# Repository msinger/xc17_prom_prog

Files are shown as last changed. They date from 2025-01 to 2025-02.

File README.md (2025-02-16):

XC17xxx PROM Programmer
=======================

Tool for programming Xilinx XC17xxx families of PROM chips that are used for storing the configuration
bitstream of the Spartan FPGA.

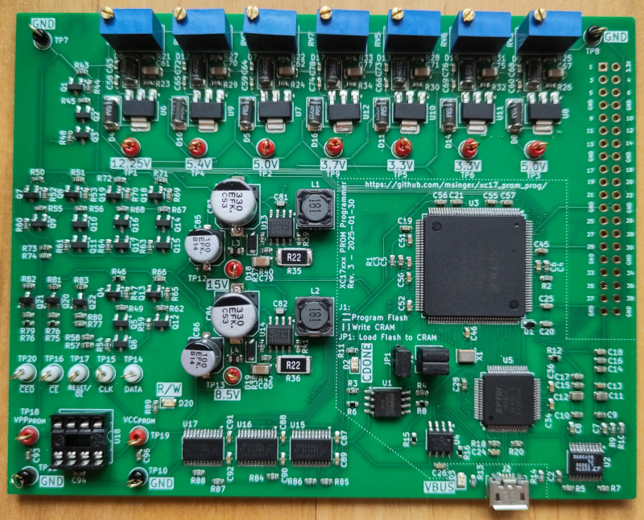
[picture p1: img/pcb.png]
PCB


I developed this programmer to be able to program the PROM chips used in the Wide-Boy64. The Wide-Boy64
CGB uses the XC1701L, and the [Wide-Boy64 AGB](http://iceboy.a-singer.de/doc/wide_boy.html) uses the XC17S20XL.

I originally thought that the Wide-Boy64 CGB uses the XC1701 chip (without the L at the end), because that's
how those chips are labeled on their package. After buying some of those XC1701 chips and reading out their
device ID, I realized that they actually are XC1701L chips. This makes sense by the way, since the Spartan
XC4010XL FPGA inside the Wide-Boy64 CGB has 3.3&nbsp;V IO voltage, which matches the XC1701L PROM. The XC1701
is a 5&nbsp;V device.

You can still buy the XC17S20XL chips here:
- https://de.aliexpress.com/item/1005006854844265.html
- https://www.win-source.net/products/detail/xilinx-inc/xc17s20lpc.html
- https://www.win-source.net/products/detail/xilinx-inc/xc17s20xlpd8c.html

You can still buy a very limited supply of the XC1701L chips here:
- https://www.win-source.net/products/detail/xilinx-inc/xc1701pd8c.html

The Xilinx datasheets recommend the XC17512L to be used with the Spartan XC4010XL (which is the FPGA used in
the Wide-Boy64 CGB). So, the XC17512L could be used instead of the XC1701L.

Files in this repo
------------------

| File/Folder | Description |
| --- | --- |
| ./pcb/xc17\_prom\_prog/ | KiCad project. |
| ./pcb/xc17\_prom\_prog/bom.ods | Bill of materials (BOM) needed to populate the PCB. |
| ./pcb/lib/ | KiCad symbol libraries used in KiCad project. |
| ./ftdi/xc17\_prom\_prog\_ftdi\_template.xml | Template for configuring the FTDI chip on the PCB. |
| ./hdl/ | Verilog project that generates the configuration for the iCE40 FPGA. |
| ./csharp/ | C# project that builds the command line tool for using the programmer. |

List of supported chips
-----------------------

I designed the programmer to be able to program the chips listed in the table below. Those are the ones I was able
to find the "Programmer Qualification Specification" datasheets for. Maybe it can be modified to work for other
variants of those PROM chips when more datasheets are found.

| PROM type | ID | Voltage group | Word size (bit) | Density (bit) | N<sub>IDCLK</sub> | N<sub>RSTCLK</sub> | T<sub>PGM</sub> (&micro;s) | T<sub>PGM1</sub> (&micro;s) | T<sub>PRST</sub> (&micro;s) |
| :--- | :--- | :---: | ---: | ---: | ---: | ---: | ---: | ---: | ---: |
| XC1736E | 0xED | A | 32 | 36288 | 2056 | 2048 | 1000 | N/A | 5000 |
| XC1765E | 0xFD | A | 32 | 65536 | 2056 | 2048 | 1000 | N/A | 5000 |
| XC1765X aka XC1765EL | 0xFC | B | 32 | 65536 | 2056 | 2048 | 1000 | N/A | 5000 |
| XC17128E | 0x8D | A | 64 | 131072 | 4600 | 4104 | 1000 | N/A | 5000 |
| XC17128X aka XC17128EL | 0x8C | B | 64 | 131072 | 4600 | 4104 | 1000 | N/A | 5000 |
| XC17256E | 0xAD | A | 64 | 262144 | 4600 | 4104 | 1000 | N/A | 5000 |
| XC17256X aka XC17256EL | 0xAC | B | 64 | 262144 | 4600 | 4104 | 1000 | N/A | 5000 |
| XC17S05 | 0xF8 | A | 32 | 65536 | 2056 | 2048 | 100 | 500 | 5000 |
| XC17S05XL | 0x87 | B | 64 | 131072 | 4600 | 4104 | 100 | 500 | 5000 |
| XC17S10 | 0x88 | A | 64 | 131072 | 4600 | 4104 | 100 | 500 | 5000 |
| XC17S10XL | 0x89 | B | 64 | 131072 | 4600 | 4104 | 100 | 500 | 5000 |
| XC17S20 | 0xA8 | A | 64 | 262144 | 4600 | 4104 | 100 | 500 | 5000 |
| XC17S20XL | 0xA9 | B | 64 | 262144 | 4600 | 4104 | 100 | 500 | 5000 |
| XC17S30 | 0xA6 | A | 64 | 262144 | 4600 | 4104 | 100 | 500 | 5000 |
| XC17S30XL | 0xA7 | B | 64 | 262144 | 4600 | 4104 | 100 | 500 | 5000 |
| XC17S40 | 0x98 | A | 64 | 524288 | 19791 | 16384 | 100 | 500 | 5000 |
| XC17S40XL | 0x99 | B | 64 | 524288 | 19791 | 16384 | 100 | 500 | 5000 |
| XC17S50XL | 0xD6 | B | 64 | 1048576 | 19791 | 16384 | 100 | 500 | 5000 |
| XC17S100XL | 0xD7 | B | 64 | 1048576 | 19791 | 16384 | 100 | 500 | 5000 |
| XC17S150XL | 0xD9 | B | 64 | 1048576 | 19791 | 16384 | 100 | 500 | 5000 |
| XC17512L | 0x9B | B | 64 | 524288 | 19791 | 16384 | 100 | 500 | 5000 |
| XC1701 | 0xDA | A | 64 | 1048576 | 19791 | 16384 | 100 | 500 | 5000 |
| XC1701L | 0xDB | B | 64 | 1048576 | 19791 | 16384 | 100 | 500 | 5000 |
| XC1702L | 0x3B | C | 64 | 2097152 | 65632 | 65536 | 100 | 200 | 400 |
| XC1704L | 0xBB | C | 64 | 4194304 | 65632 | 65536 | 100 | 200 | 400 |

The table also contains the properties that are different between the PROM types. I listed them here to have an overview;
makes it easier than reading through the datasheets over and over.

The ID column contains the device ID, which has the "density code" in its high nibble and the "algorithm code" in the
low nibble.

N<sub>IDCLK</sub> is the number of times the word address needs to be incremented to reach the manufacturer and device ID
page. N<sub>RSTCLK</sub> is the number of times the word address needs to be incremented to reach the page that stores
the reset polarity.

T<sub>PGM</sub> is the time for how long V<sub>PP1</sub> needs to be applied to program a word. T<sub>PGM1</sub> is the
time that V<sub>PP1</sub> needs to be applied for retries when programming failed. Not all PROM types support alternating
programming and verifying on a word for word basis, so not all of them can do retries. T<sub>PRST</sub> is the time for
how long V<sub>PP1</sub> needs to be applied to program the reset polarity.

The PROMs can be divided into three different "voltage groups", which define what voltages need to be applied to the
VCC and VPP pins:

| Group | V<sub>CC</sub>, V<sub>PP</sub>, V<sub>CCVFY</sub> | V<sub>CCP</sub>, V<sub>CCNOM</sub>, V<sub>PPNOM</sub> | V<sub>PP1</sub> | V<sub>PP2</sub> | V<sub>PPVFY</sub> |
| :---: | ---: | ---: | ---: | ---: | ---: |
| A | 5&nbsp;V | 5&nbsp;V | 12.25&nbsp;V | 5.4&nbsp;V | 5.4&nbsp;V |
| B | 3.3&nbsp;V | 5&nbsp;V | 12.25&nbsp;V | 5.4&nbsp;V | 3.7&nbsp;V |
| C | 3.3&nbsp;V | 3.3&nbsp;V | 12.25&nbsp;V | 3.7&nbsp;V | 3.7&nbsp;V |

PCB Specification
-----------------

I would recommend using the ZIP file from the latest github release, which contains the Gerber and drill files. Use these
parameters for ordering the PCB:

| Parameter | Value |
| --- | --- |
| Size | 123&nbsp;x&nbsp;95&nbsp;mm |
| Layers | 2 |
| Min hole size | 0.3&nbsp;mm |
| Min track/spacing | 6/6&nbsp;mil |
| Surface finish | ENIG |

The PCB doesn't contain any vias in pads.

PCB population
--------------

There are two ways to populate the PCB:
* Fully populated, including FPGA and FTDI.
  - Programmer doesn't require any additional hardware.
* Partially populated, leaving out the parts inside the dotted area.
  - Programmer needs to be plugged into an
    [iCE40-HX8K Breakout Board](https://www.latticesemi.com/Products/DevelopmentBoardsAndKits/iCE40HX8KBreakoutBoard.aspx).
  - The HX8K Breakout Board needs to be connected via USB to the PC.
  - The programmer PCB needs power over the USB port, but no data connection.

There are some parts that aren't easy to solder by hand, so if you want to save yourself some trouble, you can get
an HX8K Breakout Board. You don't need a cable to connect the two. Just solder a pin header (J3) at the bottom side
of the programmer PCB, you can plug it directly into the already soldered pin sockets of the HX8K Breakout Board (J2).

IF YOU FULLY POPULATED THE PCB, DO _**NOT**_ CONNECT IT TO AN HX8K BREAKOUT BOARD.

The [BOM](pcb/xc17_prom_prog/bom.ods) contains the parts required to fully populate the PCB. If you plan to only
partially populate it, make sure you don't order the non-required expensive parts like FPGA, FTDI and the LT3030
regulator.

FTDI configuration
------------------

The FTDI chip needs to be configured correctly, otherwise the FPGA can't be programmed. The FTDI configuration is held
in the small EEPROM chip (U4). It is programmed via USB using the FT\_PROG utility that you can download from the
[FTDI website](https://ftdichip.com/utilities/). FT\_PROG requires Windows. It also works from inside a Windows 10 VM
running on VirtualBox.

Program the [template file](ftdi/xc17_prom_prog_ftdi_template.xml) from this repository into the EEPROM. Make sure the
EEPROM is erased first.

Build FPGA bitstream
--------------------

To build the bitstream for the FPGA, you need the following tools:
* [yosys](https://github.com/YosysHQ/yosys)
* [nextpnr](https://github.com/YosysHQ/nextpnr)
* [icestorm](https://github.com/YosysHQ/icestorm)
* Plus all the standard development tools like gnumake, autoconf, automake, m4

On Fedora, you can use the following command line to install everything:

```
dnf install yosys nextpnr icestorm make autoconf automake m4
```

Inside the `hdl` directory of the repository, run the following commands to build the bitstream for a fully populated
PCB:

```
autoreconf -i
./configure --enable-board=xc17_prom_prog
make
```

If you've partially populated the PCB and connected it to the HX8K Breakout Board, then use the following commands
instead:

```
autoreconf -i
./configure --enable-board=hx8k_brk
make
```

Program FPGA bitstream into Flash
---------------------------------

The FPGA bitstream needs to be programmed into the flash chip on the PCB or HX8K Breakout Board via USB.

On a fully populated PCB, make sure to put the J1 jumpers into the "Program Flash" configuration, which is
horizontal, like it is indicated on the PCB silk print. JP1 has to be bridged as well. If you want to flash the HX8K
Breakout Board, read the documentation for that. Once the jumpers are placed correctly, you don't have to fiddle
with them anymore. Other jumper configurations are only for development, when you want to test a new FPGA
configuration without burning it into the flash. So you could also bridge the jumpers directly with solder or small
wires on the PCB.

If you've built the FPGA bitstream yourself, you can run the following command inside the `hdl` directory to program
the bitstream:

```
make prog
```

If you want to program a prebuilt release that you've downloaded from github, use the following command:

```
iceprog xc17_prom_prog.bin
```

I haven't tried it, but it should also be possible to use the
[Lattice iCEcube2 Software](https://www.latticesemi.com/en/Products/DesignSoftwareAndIP/FPGAandLDS/iCEcube2)
to program either the `asc` file or the `bin` file.

The green LED D2 (labeled CDONE) indicates that the FPGA has successfully loaded the configuration from the
flash into its configuration RAM. So, on a fully populated PCB, this LED should switch on after the flash was
programmed correctly, every time you power up the board (with the correct jumper configuration described above).
The HX8K Breakout Board also has such an LED (D10) near the jumpers.

Build the command line tool
---------------------------

For building the C# command line tool on Linux, you need the Mono framework and the standard tools gnumake, autoconf,
automake and m4.

For building it on Windows, you need the .NET Framework and some POSIX-like environment for building: Either Cygwin or
Msys2. Gnumake, autoconf, automake and m4 need to be installed in that environment. The C# compiler executable (csc.exe)
must also be callable in your build environment. Make sure it is in `$PATH`.

Run the following commands inside the `csharp` directory of the repository to build the command line tool:

```
autoreconf -i
./configure
make
```

If you want, you can install it with `make install`.

Calibration and testing of PCB
------------------------------

After populating the PCB you have to calibrate all the voltages using the trim potentiometers at the top. Just
hold your voltage meter at the test points near the potentiometers. The target voltage that each test point should
have is labeled on the silk screen print.

If the LDOs are not providing high enough voltages, check if the step-up converters provide roughly 15&nbsp;V and
8.5&nbsp;V at test points TP12 and TP13. The 15&nbsp;V is used by the first LDO (U6) to generate the 12.25&nbsp;V.
The other six LDOs use the 8.5&nbsp;V to generate their lower voltages. In case you are wondering, the reason why
there are two 3.3&nbsp;V LDOs and two 5&nbsp;V LDOs is this: One of each is there for providing the VCC voltage for
the PROM, the other one (of each) is there for providing the VPP voltage. We can't use the same LDOs for VCC and
VPP, because VPP will be switched to 12.25&nbsp;V for issuing the programming pulses. There is a short moment during
switching where the 12.25&nbsp;V and the lower voltage (3.3&nbsp;V or 5&nbsp;V) will both be connected to VPP at the
same time. At this moment, the 12.25&nbsp;V will back flow to the other LDO. If we'd use the same LDO, then the
12.25&nbsp;V would also reach the VCC pin of the PROM, which is not good. VCC needs to be constant at all time, and
it can't handle 12&nbsp;V. Only VPP can switch around.

Before trying to read or program an actual PROM chip, you first should do some tests to make sure the PCB is
working correctly.

Connect the PCB via USB and run the command line tool with the following options:

```
xc17_prom_prog.exe COMMPORT --test-echo
```

Replace *`COMMPORT`* with the correct serial port. On Windows this would be `COM2:` or something. On Linux it is
something like `/dev/ttyUSB1`. The FTDI chip has two serial ports. Usually, the first one is the one that is used
for programming the flash chip (U1) that holds the FPGA bitstream. The second port is the one we need most likely,
so try this one first. Of course, on Linux you have to call the command with `mono`, like this:

```
mono xc17_prom_prog.exe /dev/ttyUSB1 --test-echo
```

`--test-echo` just tests the serial communication and the BRAM inside the FPGA.

Next, we can test the voltage switching MOSFETs:

```
xc17_prom_prog.exe COMMPORT --test-voltage VOLTAGE
```

Again, replace *`COMMPORT`* with the actual port. For *`VOLTAGE`* insert one of the following:

 - `vcc-3v3`
 - `vcc-5v`
 - `vpp-3v3`
 - `vpp-3v7`
 - `vpp-5v`
 - `vpp-5v4`
 - `vpp-12v25`
 - `off`

For example, `vcc-3v3` will switch 3.3&nbsp;V onto the VCC pin of the PROM. (Don't actually put a PROM chip
into the socket when testing the voltages, please!) You can measure that with your voltage meter at test point
TP19. `vpp-5v4` will switch 5.4&nbsp;V onto the VPP pin at test point TP18, and so on. This test option only
enables one single voltage at a time, so don't worry, you can't make short circuits. `off` switches all MOSFETs
off, as the name implies. The red LED (D20) signals whenever at least one of the two pins (VCC, VPP) is powered
to indicate that you shouldn't insert or remove the chip right now.

There are actually three other options that can be inserted for *`VOLTAGE`* (`vcc-gnd`, `vpp-gnd` and
`vpp-gnd-weak`), but you can't measure anything there, because they are pulling the respective pin to ground.

If the voltage switching works, we should test if the 12.25&nbsp;V pulse looks okay using an oscilloscope. Hook
up one probe to test point TP18 (VPP<sub>PROM</sub>) and one to TP19 (VCC<sub>PROM</sub>). Configure the trigger
to around ~8&nbsp;V on the probe connected to VPP<sub>PROM</sub>, so we can trigger when VPP raises from
5&nbsp;V to 12.25&nbsp;V. Then run this command:

```
xc17_prom_prog.exe COMMPORT --prom xc17s20xl --detect
```

`--prom xc17s20xl` configures the programmer to use the voltages required by the XC17S20XL PROM chip (which is
used in the Wide-Boy64 AGB). This PROM chip is a 3.3&nbsp;V device, but it needs to be powered with 5&nbsp;V
to enter "programming mode". `--detect` makes the programmer just read the manufacturer and device IDs of the
PROM chip, without reading or programming anything else. For reading the IDs, the PROM has to enter "programming
mode", which sounds counterintuitive, but that's how it's done. So, the programmer will switch VCC and VPP to
5&nbsp;V. Then shortly after switching them to 5&nbsp;V, it will issue a short pulse of 12.25&nbsp;V on VPP.

On the oscilloscope we want to check the following things:

 * There should be no over and/or under shooting when the voltage on VPP raises from 5&nbsp;V to 12.25&nbsp;V
   and falls back down to 5&nbsp;V.
 * The raising and falling of the voltage on VPP shouldn't take much longer than 5&nbsp;&micro;s.
 * According to the datasheets, VCC must stay stable within &plusmn;50&nbsp;mV. I wasn't able to comply with
   that. My VCC was always swinging a bit more when the 12.25&nbsp;V ramps up on VPP. I couldn't figure out
   why this happens and how to fix it. Just make sure VCC looks reasonable, programming the PROM will work
   anyway.

If VPP takes too long to fall down to 5&nbsp;V, then the resistor R82 is probably too big and you should try
a smaller one. If VPP drops below 5&nbsp;V or if it is unstable or oscillating for some microseconds after
falling down, then resistor R82 could be too small. Try a bigger one in that case.

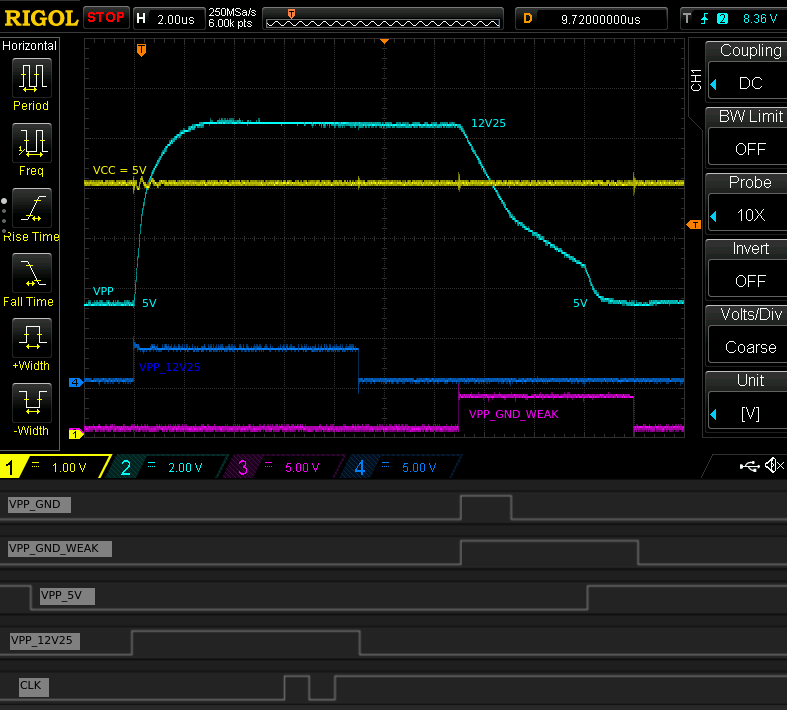
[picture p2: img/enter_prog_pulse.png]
Enter programming mode pulse


This picture shows VCC (yellow) and VPP (cyan) during the 12.25&nbsp;V pulse. The dark blue and purple channels
are added, so I can correctly photoshop the additional signals from the logic analyzer underneath the
oscilloscope screenshot. You can see VCC getting a bit unstable while VPP rises to 12.25&nbsp;V. There is a
delay of 4&nbsp;&micro;s between switching off the 5&nbsp;V LDO and switching on the 12.25&nbsp;V LDO for VPP.
This delay is needed, because when switching off, it takes 2 or 3&nbsp;&micro;s until the gates of the MOSFETs
get drained and the MOSFETs actually switch off. I had chosen a slightly longer delay to make sure that the
5 and 12.25&nbsp;V LDOs are not switched on at the same time, because this would allow the 12.25&nbsp;V to
backflow through the diode (D5) above the 5&nbsp;V LDO. This would destabilize both voltages and takes a long
time for VPP to climb up to 12.25&nbsp;V due to the near short circuit through the diode. The same
4&nbsp;&micro;s pause exists at the end of the pulse, where the 12.25&nbsp;V gets drained by switching on the
VPP\_GND and VPP\_GND\_WEAK signals. VPP\_GND switches on the NPN transistor Q20 to quickly drain VPP down
towards GND. VPP\_GND\_WEAK switches on Q21 to drain VPP through resistor R82. VPP\_GND is only enabled for
2&nbsp;&micro;s. We don't want to drain VPP lower than 5&nbsp;V. We could leave it enabled for longer, but
I want to stay on the safe side, we need to consider tolerances of the BC850 transistors. VPP\_GND\_WEAK is
enabled for 7&nbsp;&micro;s and VPP\_5V (which enables the 5&nbsp;V LDO) overlaps with it for 2&nbsp;&micro;s.
The LDO is able to sustain its output voltage through the resistor R82. By having them overlap, we can make
sure that VPP really drops to 5&nbsp;V within 5 or 6&nbsp;&micro;s. For newer chips that use a
V<sub>PPNOM</sub> of 3.3&nbsp;V instead of 5, VPP\_GND\_WEAK will stay enabled for a total of
11&nbsp;&micro;s, because we need to drain VPP a bit more. The overlap with VPP\_3V3 would be 6&nbsp;&micro;s
in that case.

Next, we want to check the programming pulse. It is basically the same, but it will fall down to 5.4&nbsp;V
instead of 5&nbsp;V, and it stays at 12.25&nbsp;V for a much longer time. To make the programmer generate
programming pulses, you can run the following command without a PROM chip inserted into the socket:

```
xc17_prom_prog.exe COMMPORT --prom xc17s20xl --force-program TESTFILE
```

This will run the programming algorithm without stopping on errors, like not detecting a PROM. It will try
to program the file *`TESTFILE`*. You can select any file for testing, it doesn't matter, we don't want to
look at the data. It must not contain only 0xFF though, because words that only consist of 1's will be
skipped during programming and will not cause a pulse, because that is the blank state of the chip. So on
Linux you could use `/dev/zero` or `/dev/random` for testing, but not `/dev/null`, because that will
immediately signal the end of file and then only 0xFF would be assumed for programming.

To trigger on the programming pulses with an oscilloscope can be tricky, because the first two or three
pulses will be the same that we have already tested, because the programmer needs to bring the chip into
"programming mode" first. We want to measure any of the later pulses. Maybe your oscilloscope supports
defining a count, so that you can let it trigger at the fourth or fifth rising edge. If not, it's okay. I
just pressed enter on the command line, and then half a second later I hit the "SINGLE" button on my
oscilloscope to arm it, so it triggers on a later pulse. It may take some tries to get the timing right.

Check for the same criteria as before. If you want, you can repeat those tests with `--prom xc1702l`. This
particular PROM type uses 3.3&nbsp;V in programming mode, which requires a slightly longer timing to let
VPP drop from 12.25&nbsp;V to 3.3&nbsp;V or 3.7&nbsp;V. Testing for this PROM type isn't necessary if you
just want to use the programmer to program PROMs for Wide-Boys. Both of the Wide-Boy types are using PROMs
that run on 5&nbsp;V in programming mode.

Just for fun, here is a zoomed out overview of a complete programming operation of a XC17S20XL PROM chip
with the Wide-Boy 64 AGB bitstream:

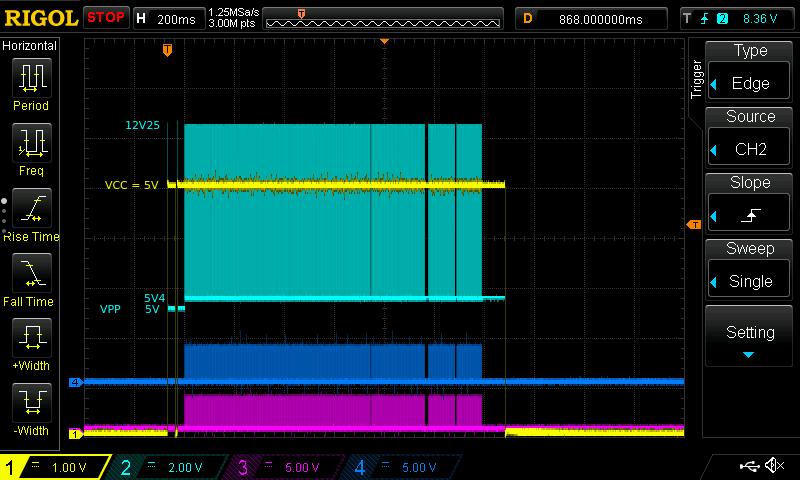
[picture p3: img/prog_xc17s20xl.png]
Programming Wide-Boy64 AGB bitstream to XC17S20XL PROM


You can see how VCC and VPP start at 5&nbsp;V. VPP spikes up to 12.25&nbsp;V a few times at the very
beginning, until it then changes between 5.4&nbsp;V and 12.25&nbsp;V while programming all the data and
doing margin verifies every 64 bits. The whole process takes just 1.4 seconds. You can also see some gaps
near the end of programming. These gaps happen when the C# tool running on the PC isn't providing the data
fast enough over the serial port. Gaps can also happen if there is nothing to program due to larger areas
filled with 0xff.

Command line options
--------------------

| Option | Description |
| --- | --- |
| <code>&#x2011;&#x2011;help</code> | Prints summary of all options. |
| <code>&#x2011;&#x2011;prom&nbsp;PROM</code> | Configures the programmer to handle the specific PROM chip. Replace `PROM` with the type name of any of the supported PROM chips listed in the PROM type table above, like `xc17s20xl` for example. This option must be used in combination with any of the other options that specify the operation. |
| <code>&#x2011;&#x2011;test&#x2011;echo</code> | Tests communication and BRAM buffers on programmer. |
| <code>&#x2011;&#x2011;test&#x2011;voltage&nbsp;VOLTAGE</code> | Don't use this option when a PROM is inserted! Switch on a single supply `VOLTAGE` and switch off all others for testing. `VOLTAGE` can be one of <code>vcc&#x2011;gnd</code>, <code>vcc&#x2011;3v3</code>, <code>vcc&#x2011;5v</code>, <code>vpp&#x2011;gnd</code>, <code>vpp&#x2011;gnd&#x2011;weak</code>, <code>vpp&#x2011;3v3</code>, <code>vpp&#x2011;3v7</code>, <code>vpp&#x2011;5v</code>, <code>vpp&#x2011;5v4</code>, <code>vpp&#x2011;12v25</code>, `off`. |
| <code>&#x2011;&#x2011;detect</code> | Detect presence of the PROM chip by reading manufacturer and device ID. The <code>&#x2011;&#x2011;prom</code> option must be used to specify the PROM type. |
| <code>&#x2011;&#x2011;blank</code> | Performs blank check on a PROM chip. Returns 0 if the chip is blank, otherwise 1. Whether the reset polarity of the chip was programmed does not affect the result. The <code>&#x2011;&#x2011;prom</code> option must be used to specify the PROM type. |
| <code>&#x2011;&#x2011;read&#x2011;reset</code> | Reads reset polarity of the chip. Returns 0 if the reset polarity was programmed to be active low; otherwise, if it is not programmed (active high), it returns 1. The <code>&#x2011;&#x2011;prom</code> option must be used to specify the PROM type. |
| <code>&#x2011;&#x2011;read&nbsp;OUTFILE</code> | Reads the content of the chip and writes it into `OUTFILE`. The <code>&#x2011;&#x2011;prom</code> option must be used to specify the PROM type. |
| <code>&#x2011;&#x2011;margin&#x2011;read&nbsp;OUTFILE</code>  | Reads the content of the chip and writes it into `OUTFILE`. Applies a voltage margin of 0.4&nbsp;V between VCC and VPP during the read operation. This margin makes it more likely to misread bits that haven't been charged sufficiently during programming. So you can use this read option when you want to challenge the "health" or "quality" of the programmed bits. The <code>&#x2011;&#x2011;prom</code> option must be used to specify the PROM type. |
| <code>&#x2011;&#x2011;verify&nbsp;INFILE</code> | Verifies that the content of the chip matches the content of `INFILE`. The <code>&#x2011;&#x2011;prom</code> option must be used to specify the PROM type. |
| <code>&#x2011;&#x2011;margin&#x2011;verify&nbsp;INFILE</code> | Verifies that the content of the chip matches the content of `INFILE`. Same as for <code>&#x2011;&#x2011;margin&#x2011;read</code> it applies a voltage margin of 0.4&nbsp;V between VCC and VPP. The <code>&#x2011;&#x2011;prom</code> option must be used to specify the PROM type. |
| <code>&#x2011;&#x2011;program&nbsp;INFILE</code> | Programs the content of `INFILE` onto the PROM chip. For chips that support a word by word verification during programming, the operation will abort as soon as a word was detected to be written incorrectly. The <code>&#x2011;&#x2011;prom</code> option must be used to specify the PROM type. |
| <code>&#x2011;&#x2011;force&#x2011;program&nbsp;INFILE</code> | Programs the content of `INFILE` onto the PROM chip. This option should be used for measuring the programming pulse with an oscilloscope. It skips the PROM chip detection and ignores verification errors, so it will run through even if no chip is inserted into the socket. The <code>&#x2011;&#x2011;prom</code> option must be used to specify the PROM type. |
| <code>&#x2011;&#x2011;program&#x2011;reset</code> | Programs the reset polarity of the PROM chip to be active low. If not programmed, the reset polarity is active high. The <code>&#x2011;&#x2011;prom</code> option must be used to specify the PROM type. |

Reading a PROM chip
-------------------

To read the content of an already programmed PROM chip, use the following command line:

```
xc17_prom_prog.exe COMMPORT --prom PROMTYPE --read OUTFILE
```

As an example, if you want to read the XC17S20XL PROM chip from a Wide-Boy64 AGB on Linux,
your command line will look something like this:

```
mono xc17_prom_prog.exe /dev/ttyUSB1 --prom xc17s20xl --read wideboy64agb_prom.bin
```

Programming a PROM chip
-----------------------

To program an image file onto a blank PROM chip, perform the following actions:

First, check if the chip is really blank:

```
xc17_prom_prog.exe COMMPORT --prom PROMTYPE --blank
```

A message will be displayed if the chip isn't blank. The reset polarity of the chip is
always printed before each operation. So you can also check that the reset is not programmed
already.

Then we can program the image file:

```
xc17_prom_prog.exe COMMPORT --prom PROMTYPE --program INFILE
```

After programming the data, you have to decide if you want to program the reset polarity to be active low.
Both Wide-Boy variants (CGB and AGB) require an active low reset of the chip. So if you want to program
the chip for use in a Wide-Boy, then you have to program the reset polarity:

```
xc17_prom_prog.exe COMMPORT --prom PROMTYPE --program-reset
```

Remember, before performing any operation, the programming tool always prints the current reset polarity.
So, the "program reset" operation will report the current reset polarity as "not programmed" (active high).
If programming the reset polarity fails, there will be an error message.

Finally, we can verify if the programming was successful:

```
xc17_prom_prog.exe COMMPORT --prom PROMTYPE --margin-verify INFILE
```

This should now also report the reset polarity as "programmed" (active low), if you have performed that
step before.

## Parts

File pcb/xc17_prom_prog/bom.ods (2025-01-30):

Designator | MPN | Qty | Link | Unit Price | Qty Price | Footprint | Value
C1,C5,C6,C13,C18,C19,C21,C22,C23,C24,C26,C27,C29,C31,C33,C34,C35,C36,C37,C38,C39,C40,C41,C42,C43,C44,C45,C46,C47,C48,C49,C50,C51,C52,C53,C54,C55,C56,C57,C58,C59,C60,C65,C66,C69,C74,C87,C88,C89,C90,C91,C92,C93,C94,C95,C96C56,C61,C62,C65,C70,C83,C84,C85,C86,C87,C88,C89,C90,C91,C92 | CL31B106KOHNFNE | 56 | https://eu.mouser.com/ProductDetail/603-CC0603MPX78BB104 | $0.017 | $0.952 | 0603 | 100nF
C2,C3,C4,C9,C14,C15,C28 | CL10A106MQ8NNND | 7 | https://eu.mouser.com/ProductDetail/187-CL10A106MQ8NNND | $0.031 | $0.217 | 0603 | 10µF
C7,C8,C20,C25 | CC0603MRX7R9BB103 | 4 | https://eu.mouser.com/ProductDetail/603-CC603MRX7R9BB103 | $0.012 | $0.048 | 0603 | 10nF
C10,C30,C32 | CL10A475KQ8NNWC | 3 | https://eu.mouser.com/ProductDetail/187-CL10A475KQ8NNWC | $0.024 | $0.072 | 0603 | 4.7µF
C11,C12 | CL21A226KQCLRNC | 2 | https://eu.mouser.com/ProductDetail/187-CL21A226KQCLRNC | $0.043 | $0.086 | 0805 | 22µF
C16,C17,C63,C64,C68,C72,C73,C76,C78 | C0603C105K4PAC7867 | 9 | https://eu.mouser.com/ProductDetail/80-C0603C105K4P7867 | $0.029 | $0.261 | 0603 | 16V 1µF
C61,C62,C67,C70,C71,C75,C77 | CL31B106KOHNFNE | 7 | https://eu.mouser.com/ProductDetail/187-CL31B106KOHNFNE | $0.046 | $0.322 | 1206 | 16V 10µF
C79,C80 | CL31A107MQHNNWE | 2 | https://eu.mouser.com/ProductDetail/187-CL31A107MQHNNWE | $0.189 | $0.378 | 1206 | 100µF
C81,C82 | GRT1885C1H152JA02D | 2 | https://eu.mouser.com/ProductDetail/81-GRT1885C1H152JA2D | $0.034 | $0.068 | 0603 | 1.5nF
C83,C84 | EEE-FK1E331P | 2 | https://eu.mouser.com/ProductDetail/667-EEE-FK1E331P | $0.404 | $0.808 | 8mm x 10.2mm | 25V 330µF
C85,C86 | EEE-FK1E101XP | 2 | https://eu.mouser.com/ProductDetail/667-EEE-FK1E101XP | $0.284 | $0.568 | 6.3mm x 7.7mm | 25V 100µF
D1 | CDBU0520 | 1 | https://eu.mouser.com/ProductDetail/750-CDBU0520 | $0.227 | $0.227 | 0603 | CDBU0520
D2,D3 | 150080GS75000 | 2 | https://eu.mouser.com/ProductDetail/710-150080GS75000 | $0.186 | $0.372 | 0805 | green
D4,D5,D6,D7,D8,D9,D10,D11,D12,D13,D14,D15,D16,D17 | SM4002 | 14 | https://eu.mouser.com/ProductDetail/637-SM4002 | $0.071 | $0.994 | MELF | 1N4002
D18,D19 | 1N5819HW-7-F | 2 | https://eu.mouser.com/ProductDetail/621-1N5819HW-F | $0.169 | $0.338 | SOD-123-2 | 1N5819
D20 | 150080RS75000 | 1 | https://eu.mouser.com/ProductDetail/710-150080RS75000 | $0.186 | $0.186 | 0805 | red
J2 | 105017-0001 | 1 | https://eu.mouser.com/ProductDetail/538-105017-0001 | $0.689 | $0.689
L1,L2 | ASPI-0704S-181M-T | 2 | https://eu.mouser.com/ProductDetail/815-ASPI-0704S-181M | $0.467 | $0.934 | 7.3mm x 7.3mm | 180µH
L3,L4 | LBR2012T1R0M | 2 | https://eu.mouser.com/ProductDetail/963-LBR2012T1R0M | $0.074 | $0.148 | 0805 | 1µH
Q1,Q4,Q7,Q8,Q13,Q18,Q19,Q20,Q21,Q22 | BC850CLT1G | 10 | https://eu.mouser.com/ProductDetail/863-BC850CLT1G | $0.026 | $0.260 | SOT-23-3 | BC850
Q2,Q3,Q5,Q6,Q9,Q10,Q11,Q12,Q14,Q15,Q16,Q17 | IRLML9301TRPBF | 12 | https://eu.mouser.com/ProductDetail/942-IRLML9301TRPBF | $0.154 | $1.848 | SOT-23-3 | IRLML9301
R1,R2 | RC0603FR-10100RL | 2 | https://eu.mouser.com/ProductDetail/603-RC0603FR-10100RL | $0.006 | $0.012 | 0603 | 100Ω
R3,R4,R6,R8,R12,R15,R16,R19,R43,R46,R50,R51,R66,R71,R72,R75,R76,R77,R84,R85,R87 | RC0603FR-1310KL | 21 | https://eu.mouser.com/ProductDetail/603-RC0603FR-1310KL | $0.006 | $0.126 | 0603 | 10kΩ
R5,R7,R14 | RC0603JR-131ML | 3 | https://eu.mouser.com/ProductDetail/603-RC0603JR-131ML | $0.006 | $0.018 | 0603 | 1MΩ
R9 | RC0603FR-07357KL | 1 | https://eu.mouser.com/ProductDetail/603-RC0603FR-07357KL | $0.007 | $0.007 | 0603 | 1% 357kΩ
R10 | RC0603FR-07210KL | 1 | https://eu.mouser.com/ProductDetail/603-RC0603FR-07210KL | $0.006 | $0.006 | 0603 | 1% 210kΩ
R11,R13,R17,R20,R21,R45,R49,R55,R56,R62,R67,R68,R89 | RC0603FR-072K05L | 13 | https://eu.mouser.com/ProductDetail/603-RC0603FR-072K05L | $0.005 | $0.065 | 0603 | 1% 2.05kΩ
R18 | RC0603FR-1012KL | 1 | https://eu.mouser.com/ProductDetail/603-RC0603FR-1012KL | $0.007 | $0.007 | 0603 | 1% 12kΩ
R22,R25 | RC0603FR-07665RL | 2 | https://eu.mouser.com/ProductDetail/603-RC0603FR-07665RL | $0.007 | $0.014 | 0603 | 1% 665Ω
R23,R24,R26,R29,R30,R32,R34 | RC0603FR-10240RL | 7 | https://eu.mouser.com/ProductDetail/603-RC0603FR-10240RL | $0.006 | $0.042 | 0603 | 1% 240Ω
R27 | RC0603FR-07750RL | 1 | https://eu.mouser.com/ProductDetail/603-RC0603FR-07750RL | $0.006 | $0.006 | 0603 | 1% 750Ω
R28,R31 | RC0603FR-07340RL | 2 | https://eu.mouser.com/ProductDetail/603-RC0603FR-07340RL | $0.007 | $0.014 | 0603 | 1% 340Ω
R33,R44,R47,R52,R53,R65,R69,R70,R78,R79,R80 | RC0603FR-07422RL | 11 | https://eu.mouser.com/ProductDetail/603-RC0603FR-07422RL | $0.005 | $0.055 | 0603 | 1% 422Ω
R35,R36 | ERJ-1TRQFR22U | 2 | https://eu.mouser.com/ProductDetail/667-ERJ-1TRQFR22U | $0.311 | $0.622 | 2512 | 1W 0.22Ω
R37 | RC0603FR-104K3L | 1 | https://eu.mouser.com/ProductDetail/603-RC0603FR-104K3L | $0.007 | $0.007 | 0603 | 1% 4.3kΩ
R38 | RC0603FR-078K2L | 1 | https://eu.mouser.com/ProductDetail/603-RC0603FR-078K2L | $0.007 | $0.007 | 0603 | 1% 8.2kΩ
R39,R41 | RC0603FR-07180RL | 2 | https://eu.mouser.com/ProductDetail/603-RC0603FR-07180RL | $0.006 | $0.012 | 0603 | 1% 180Ω
R40,R42 | RC0603FR-1047K5L | 2 | https://eu.mouser.com/ProductDetail/603-RC0603FR-1047K5L | $0.005 | $0.010 | 0603 | 1% 47.5kΩ
R48,R54,R59,R60,R61,R63,R64 | RC0603FR-131R5L | 7 | https://eu.mouser.com/ProductDetail/603-RC0603FR-131R5L | $0.011 | $0.077 | 0603 | 1% 1.5Ω
R57,R73,R81,R83 | RC0603FR-100RL | 4 | https://eu.mouser.com/ProductDetail/603-RC0603FR-100RL | $0.006 | $0.024 | 0603 | 0Ω
R58,R74,R86,R88 | RC0603JR-10100KL | 4 | https://eu.mouser.com/ProductDetail/603-RC0603JR-10100KL | $0.006 | $0.024 | 0603 | 100kΩ
R82 | RK73H1JTTD47R0F | 1 | https://eu.mouser.com/ProductDetail/660-RK73H1JTTD47R0F | $0.008 | $0.008 | 0603 | 1% 47Ω
RV1,RV2,RV3,RV4,RV5,RV6,RV7 | PV36X101C01B00 | 7 | https://eu.mouser.com/ProductDetail/81-PV36X101C01B00 | $1.580 | $11.060 |  | linear 100Ω
U1 | W25Q32JVSSIM TR | 1 | https://eu.mouser.com/ProductDetail/454-W25Q32JVSSIMTR | $0.655 | $0.655 | SOIC-8 208-mil | 4M x 8bit
U2 | LT3030EFE#PBF | 1 | https://eu.mouser.com/ProductDetail/584-LT3030EFE%23PBF | $7.660 | $7.660 | ETSSOP-20
U3 | iCE40HX4K-TQ144 | 1 | https://eu.mouser.com/ProductDetail/842-ICE40HX4K-TQ144 | $9.560 | $9.560 | TQFP-144
U4 | 93LC56BT-I/SN | 1 | https://eu.mouser.com/ProductDetail/579-93LC56BT-I-SN | $0.328 | $0.328 | SOIC-8 150-mil | 128 x 16bit
U5 | FT2232HL-REEL | 1 | https://eu.mouser.com/ProductDetail/895-FT2232HL | $5.280 | $5.280 | LQFP-64
U6,U7,U8,U9,U10,U11,U12 | LM317DCYRG3 | 7 | https://eu.mouser.com/ProductDetail/595-LM317DCYRG3 | $0.404 | $2.828 | SOT-223-4 | LM317
U13,U14 | MC33063ADR | 2 | https://eu.mouser.com/ProductDetail/595-MC33063ADR | $0.364 | $0.728 | SOIC-8 150-mil | MC33063
U15,U16,U17 | 74LVC8T245PW,118 | 3 | https://eu.mouser.com/ProductDetail/771-74LVC8T245PW118 | $0.605 | $1.815 | TSSOP-24
X1 | ASTX-H11-12.000MHZ-T | 1 | https://eu.mouser.com/ProductDetail/815-ASTXH1112T | $4.340 | $4.340 | 3.2mm x 2.5mm | 12MHz
 |  | 257 |  |  | $55.193

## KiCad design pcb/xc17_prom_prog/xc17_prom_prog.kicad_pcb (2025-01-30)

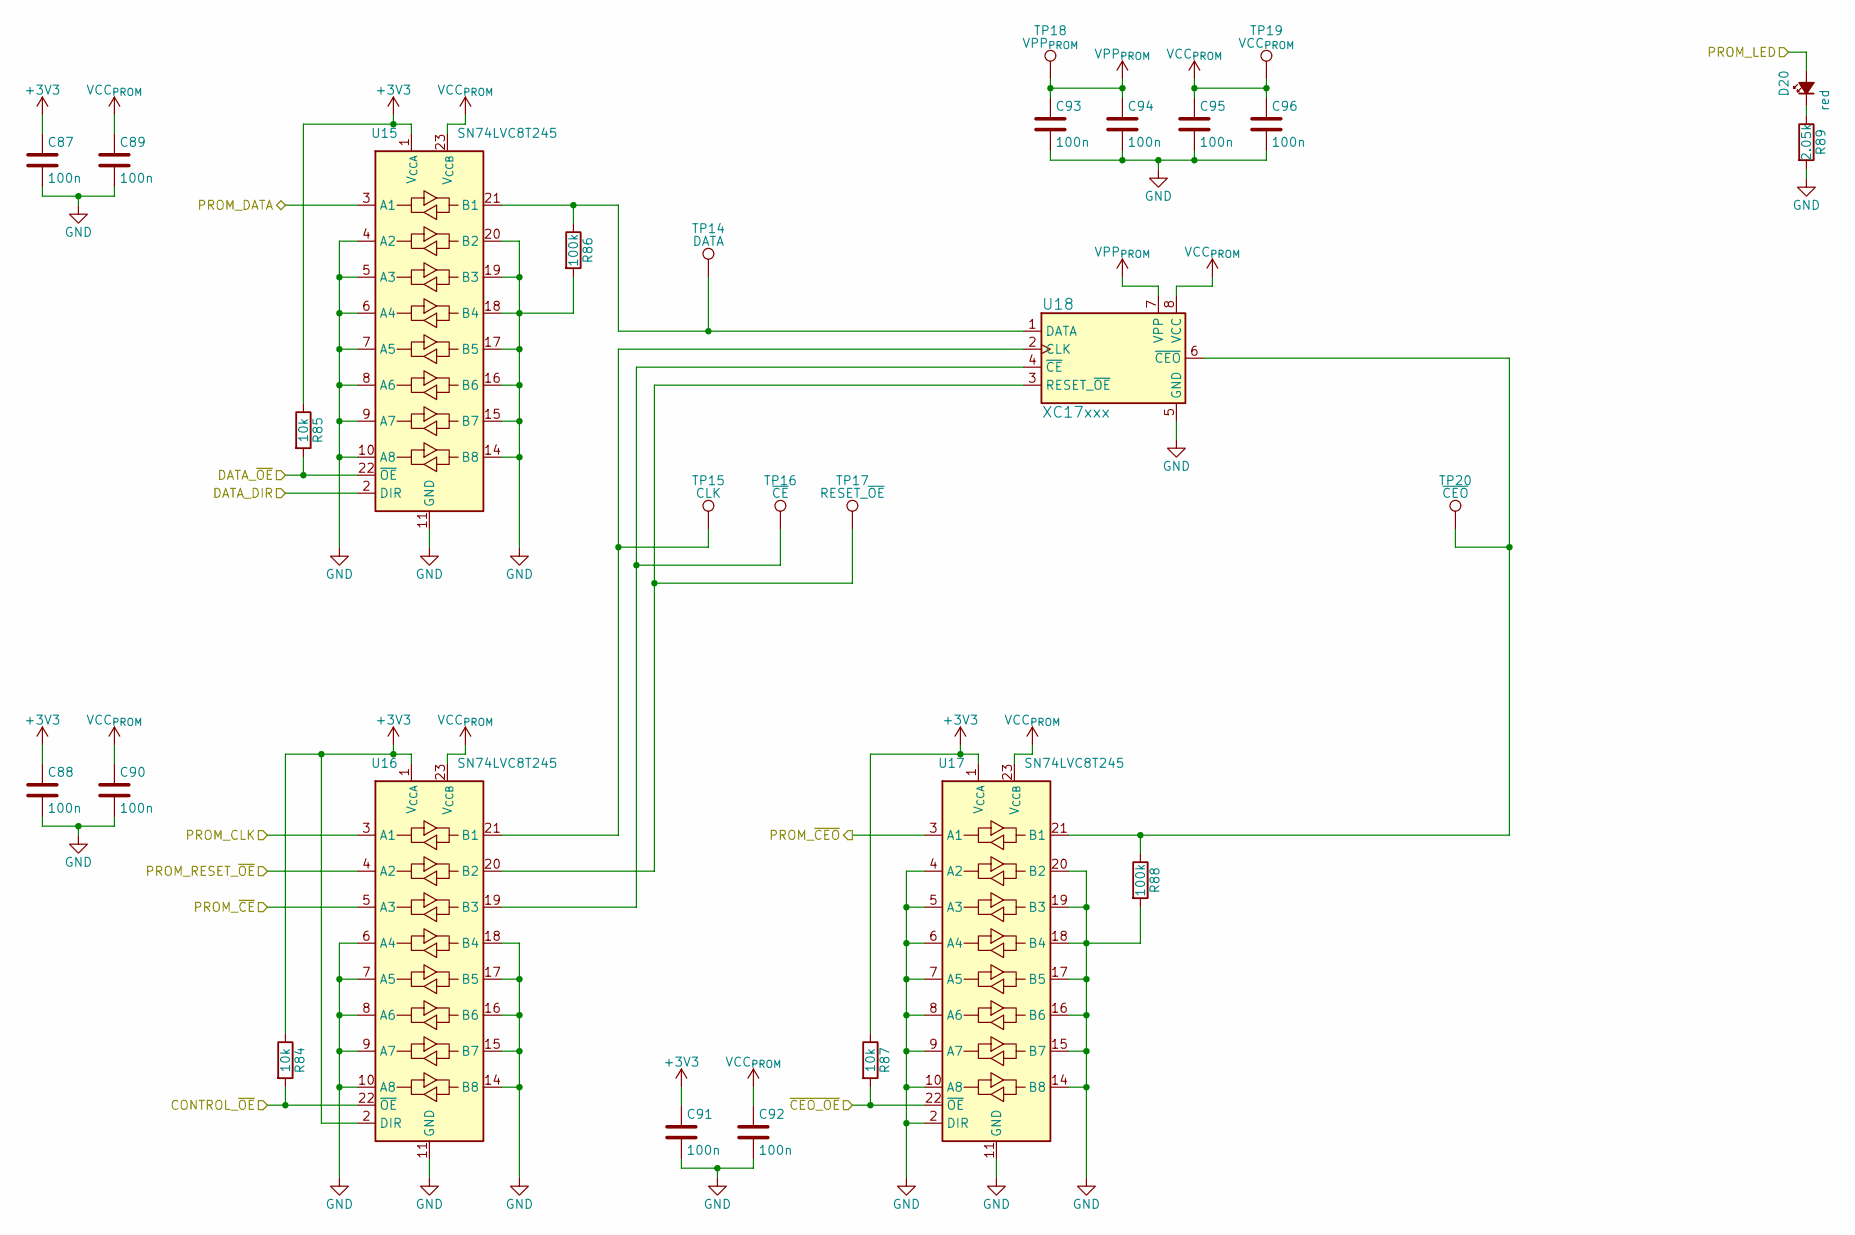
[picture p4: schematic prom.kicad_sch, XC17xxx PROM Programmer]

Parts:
C87, C88, C89, C90, C91, C92, C93, C94, C95, C96: 100n; C_0603_1608Metric
D20: red; LED_0805_2012Metric
R84, R85, R87: 10k; R_0603_1608Metric
R86, R88: 100k; R_0603_1608Metric
R89: 2.05k; R_0603_1608Metric
TP14: DATA; TestPoint_Keystone_5010-5014_Multipurpose
TP15: CLK; TestPoint_Keystone_5010-5014_Multipurpose
TP16: ~{CE}; TestPoint_Keystone_5010-5014_Multipurpose
TP17: RESET_~{OE}; TestPoint_Keystone_5010-5014_Multipurpose
TP18: VPP_{PROM}; TestPoint_Keystone_5010-5014_Multipurpose
TP19: VCC_{PROM}; TestPoint_Keystone_5010-5014_Multipurpose
TP20: ~{CEO}; TestPoint_Keystone_5010-5014_Multipurpose
U15, U16, U17: SN74LVC8T245; TSSOP-24_4.4x7.8mm_P0.65mm
U18: XC17xxx; DIP-8_W7.62mm_Socket

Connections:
+3V3: C87.1, C88.1, C91.1, R84.1, R85.1, R87.1, U15.1 (V_{CCA}), U16.1 (V_{CCA}), U16.2 (DIR), U17.1 (V_{CCA}); also elsewhere on the board
/FPGA/CONTROL_~OE: R84.2, U16.22 (~OE); also elsewhere on the board
/FPGA/DATA_DIR: U15.2 (DIR); also elsewhere on the board
/FPGA/DATA_~OE: R85.2, U15.22 (~OE); also elsewhere on the board
/FPGA/PROM_CLK: U16.3 (A1); also elsewhere on the board
/FPGA/PROM_DATA: U15.3 (A1); also elsewhere on the board
/FPGA/PROM_LED: D20.2 (A); also elsewhere on the board
/FPGA/PROM_RESET_~OE: U16.4 (A2); also elsewhere on the board
/FPGA/PROM_~CEO: U17.3 (A1); also elsewhere on the board
/FPGA/PROM_~CE: U16.5 (A3); also elsewhere on the board
/FPGA/~CEO_OE: R87.2, U17.22 (~OE); also elsewhere on the board
GND: C87.2, C88.2, C89.2, C90.2, C91.2, C92.2, C93.2, C94.2, C95.2, C96.2, R86.2, R88.2, R89.2, U15.4 (A2), U15.5 (A3), U15.6 (A4), U15.7 (A5), U15.8 (A6), U15.9 (A7), U15.10 (A8), U15.11 (GND), U15.12 (GND), U15.13 (GND), U15.14 (B8), U15.15 (B7), U15.16 (B6), U15.17 (B5), U15.18 (B4), U15.19 (B3), U15.20 (B2), U16.6 (A4), U16.7 (A5), U16.8 (A6), U16.9 (A7), U16.10 (A8), U16.11 (GND), U16.12 (GND), U16.13 (GND), U16.14 (B8), U16.15 (B7), U16.16 (B6), U16.17 (B5), U16.18 (B4), U17.2 (DIR), U17.4 (A2), U17.5 (A3), U17.6 (A4), U17.7 (A5), U17.8 (A6), U17.9 (A7), U17.10 (A8), U17.11 (GND), U17.12 (GND), U17.13 (GND), U17.14 (B8), U17.15 (B7), U17.16 (B6), U17.17 (B5), U17.18 (B4), U17.19 (B3), U17.20 (B2), U18.5 (GND); also elsewhere on the board
unnamed: D20.1 (K), R89.1
unnamed: R86.1, TP14.1, U15.21 (B1), U18.1 (DATA)
unnamed: TP15.1, U16.21 (B1), U18.2 (CLK)
unnamed: TP17.1, U16.20 (B2), U18.3 (RESET_~OE)
unnamed: TP16.1, U16.19 (B3), U18.4 (~CE)
unnamed: R88.1, TP20.1, U17.21 (B1), U18.6 (~CEO)
VCC_{PROM}: C89.1, C90.1, C92.1, C95.1, C96.1, TP19.1, U15.23 (V_{CCB}), U15.24 (V_{CCB}), U16.23 (V_{CCB}), U16.24 (V_{CCB}), U17.23 (V_{CCB}), U17.24 (V_{CCB}), U18.8 (VCC); also elsewhere on the board
VPP_{PROM}: C93.1, C94.1, TP18.1, U18.7 (VPP); also elsewhere on the board

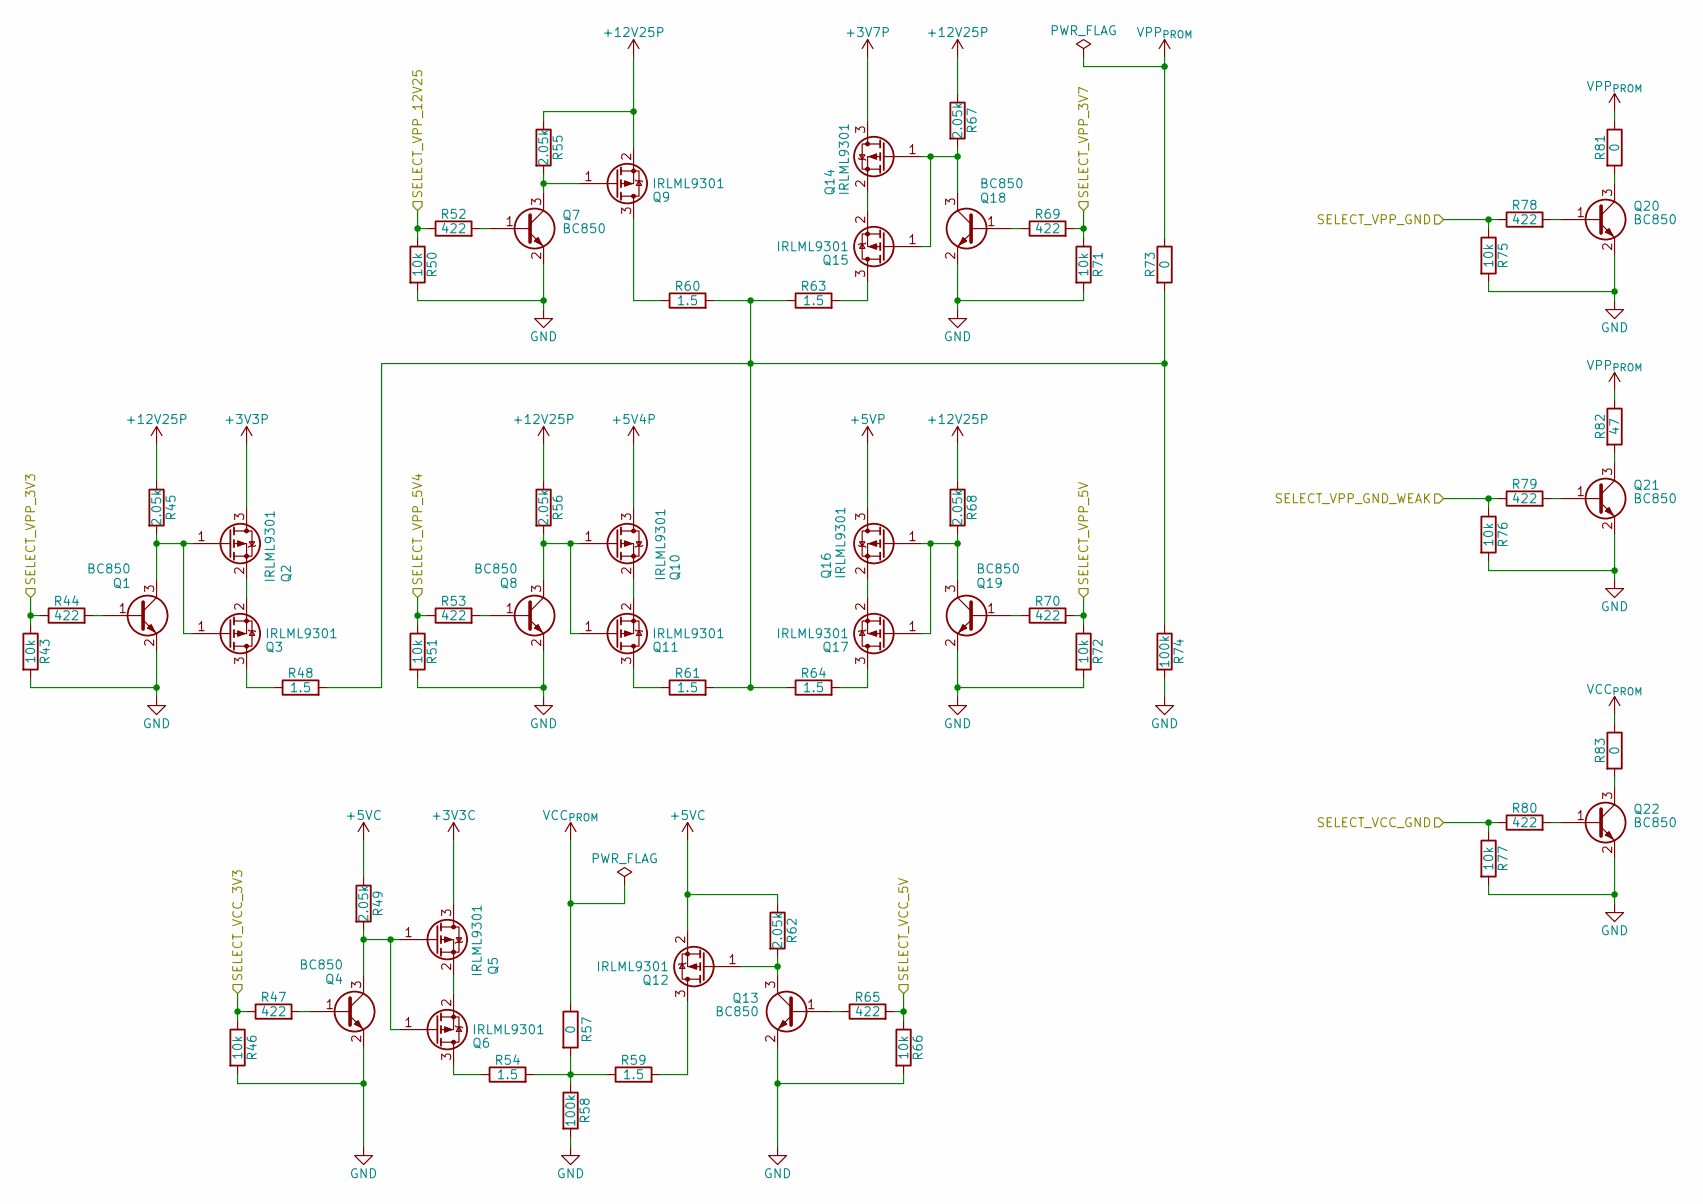
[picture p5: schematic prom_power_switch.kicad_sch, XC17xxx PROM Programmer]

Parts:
Q1, Q4, Q7, Q8, Q13, Q18, Q19, Q20, Q21, Q22: BC850; SOT-23
Q2, Q3, Q5, Q6, Q9, Q10, Q11, Q12, Q14, Q15, Q16, Q17: IRLML9301; SOT-23
R43, R46, R50, R51, R66, R71, R72, R75, R76, R77: 10k; R_0603_1608Metric
R44, R47, R52, R53, R65, R69, R70, R78, R79, R80: 422; R_0603_1608Metric
R45, R49, R55, R56, R62, R67, R68: 2.05k; R_0603_1608Metric
R48, R54, R59, R60, R61, R63, R64: 1.5; R_0603_1608Metric
R57, R73, R81, R83: 0; R_0603_1608Metric
R58, R74: 100k; R_0603_1608Metric
R82: 47; R_0603_1608Metric

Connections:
+3V3C: Q5.3 (D); also elsewhere on the board
+3V3P: Q2.3 (D); also elsewhere on the board
+3V7P: Q14.3 (D); also elsewhere on the board
+5V4P: Q10.3 (D); also elsewhere on the board
+5VC: Q12.2 (S), R49.1, R62.1; also elsewhere on the board
+5VP: Q16.3 (D); also elsewhere on the board
+12V25P: Q9.2 (S), R45.1, R55.1, R56.1, R67.1, R68.1; also elsewhere on the board
/FPGA/SELECT_VCC_3V3: R46.1, R47.1; also elsewhere on the board
/FPGA/SELECT_VCC_5V: R65.2, R66.1; also elsewhere on the board
/FPGA/SELECT_VCC_GND: R77.1, R80.1; also elsewhere on the board
/FPGA/SELECT_VPP_3V3: R43.1, R44.1; also elsewhere on the board
/FPGA/SELECT_VPP_3V7: R69.2, R71.1; also elsewhere on the board
/FPGA/SELECT_VPP_5V: R70.2, R72.1; also elsewhere on the board
/FPGA/SELECT_VPP_5V4: R51.1, R53.1; also elsewhere on the board
/FPGA/SELECT_VPP_12V25: R50.1, R52.1; also elsewhere on the board
/FPGA/SELECT_VPP_GND: R75.1, R78.1; also elsewhere on the board
/FPGA/SELECT_VPP_GND_WEAK: R76.1, R79.1; also elsewhere on the board
GND: Q1.2 (E), Q4.2 (E), Q7.2 (E), Q8.2 (E), Q13.2 (E), Q18.2 (E), Q19.2 (E), Q20.2 (E), Q21.2 (E), Q22.2 (E), R43.2, R46.2, R50.2, R51.2, R58.2, R66.2, R71.2, R72.2, R74.2, R75.2, R76.2, R77.2; also elsewhere on the board
unnamed: Q1.1 (B), R44.2
unnamed: Q1.3 (C), Q2.1 (G), Q3.1 (G), R45.2
unnamed: Q2.2 (S), Q3.2 (S)
unnamed: Q3.3 (D), R48.1
unnamed: Q4.1 (B), R47.2
unnamed: Q4.3 (C), Q5.1 (G), Q6.1 (G), R49.2
unnamed: Q5.2 (S), Q6.2 (S)
unnamed: Q6.3 (D), R54.1
unnamed: Q7.1 (B), R52.2
unnamed: Q7.3 (C), Q9.1 (G), R55.2
unnamed: Q8.1 (B), R53.2
unnamed: Q9.3 (D), R60.1
unnamed: Q8.3 (C), Q10.1 (G), Q11.1 (G), R56.2
unnamed: Q10.2 (S), Q11.2 (S)
unnamed: Q11.3 (D), R61.1
unnamed: Q12.3 (D), R59.2
unnamed: Q12.1 (G), Q13.3 (C), R62.2
unnamed: Q13.1 (B), R65.1
unnamed: Q14.1 (G), Q15.1 (G), Q18.3 (C), R67.2
unnamed: Q14.2 (S), Q15.2 (S)
unnamed: Q15.3 (D), R63.2
unnamed: Q16.1 (G), Q17.1 (G), Q19.3 (C), R68.2
unnamed: Q16.2 (S), Q17.2 (S)
unnamed: Q17.3 (D), R64.2
unnamed: Q18.1 (B), R69.1
unnamed: Q19.1 (B), R70.1
unnamed: Q20.1 (B), R78.2
unnamed: Q20.3 (C), R81.2
unnamed: Q21.1 (B), R79.2
unnamed: Q21.3 (C), R82.2
unnamed: Q22.1 (B), R80.2
unnamed: Q22.3 (C), R83.2
unnamed: R48.2, R60.2, R61.2, R63.1, R64.1, R73.2, R74.1
unnamed: R54.2, R57.2, R58.1, R59.1
VCC_{PROM}: R57.1, R83.1; also elsewhere on the board
VPP_{PROM}: R73.1, R81.1, R82.1; also elsewhere on the board

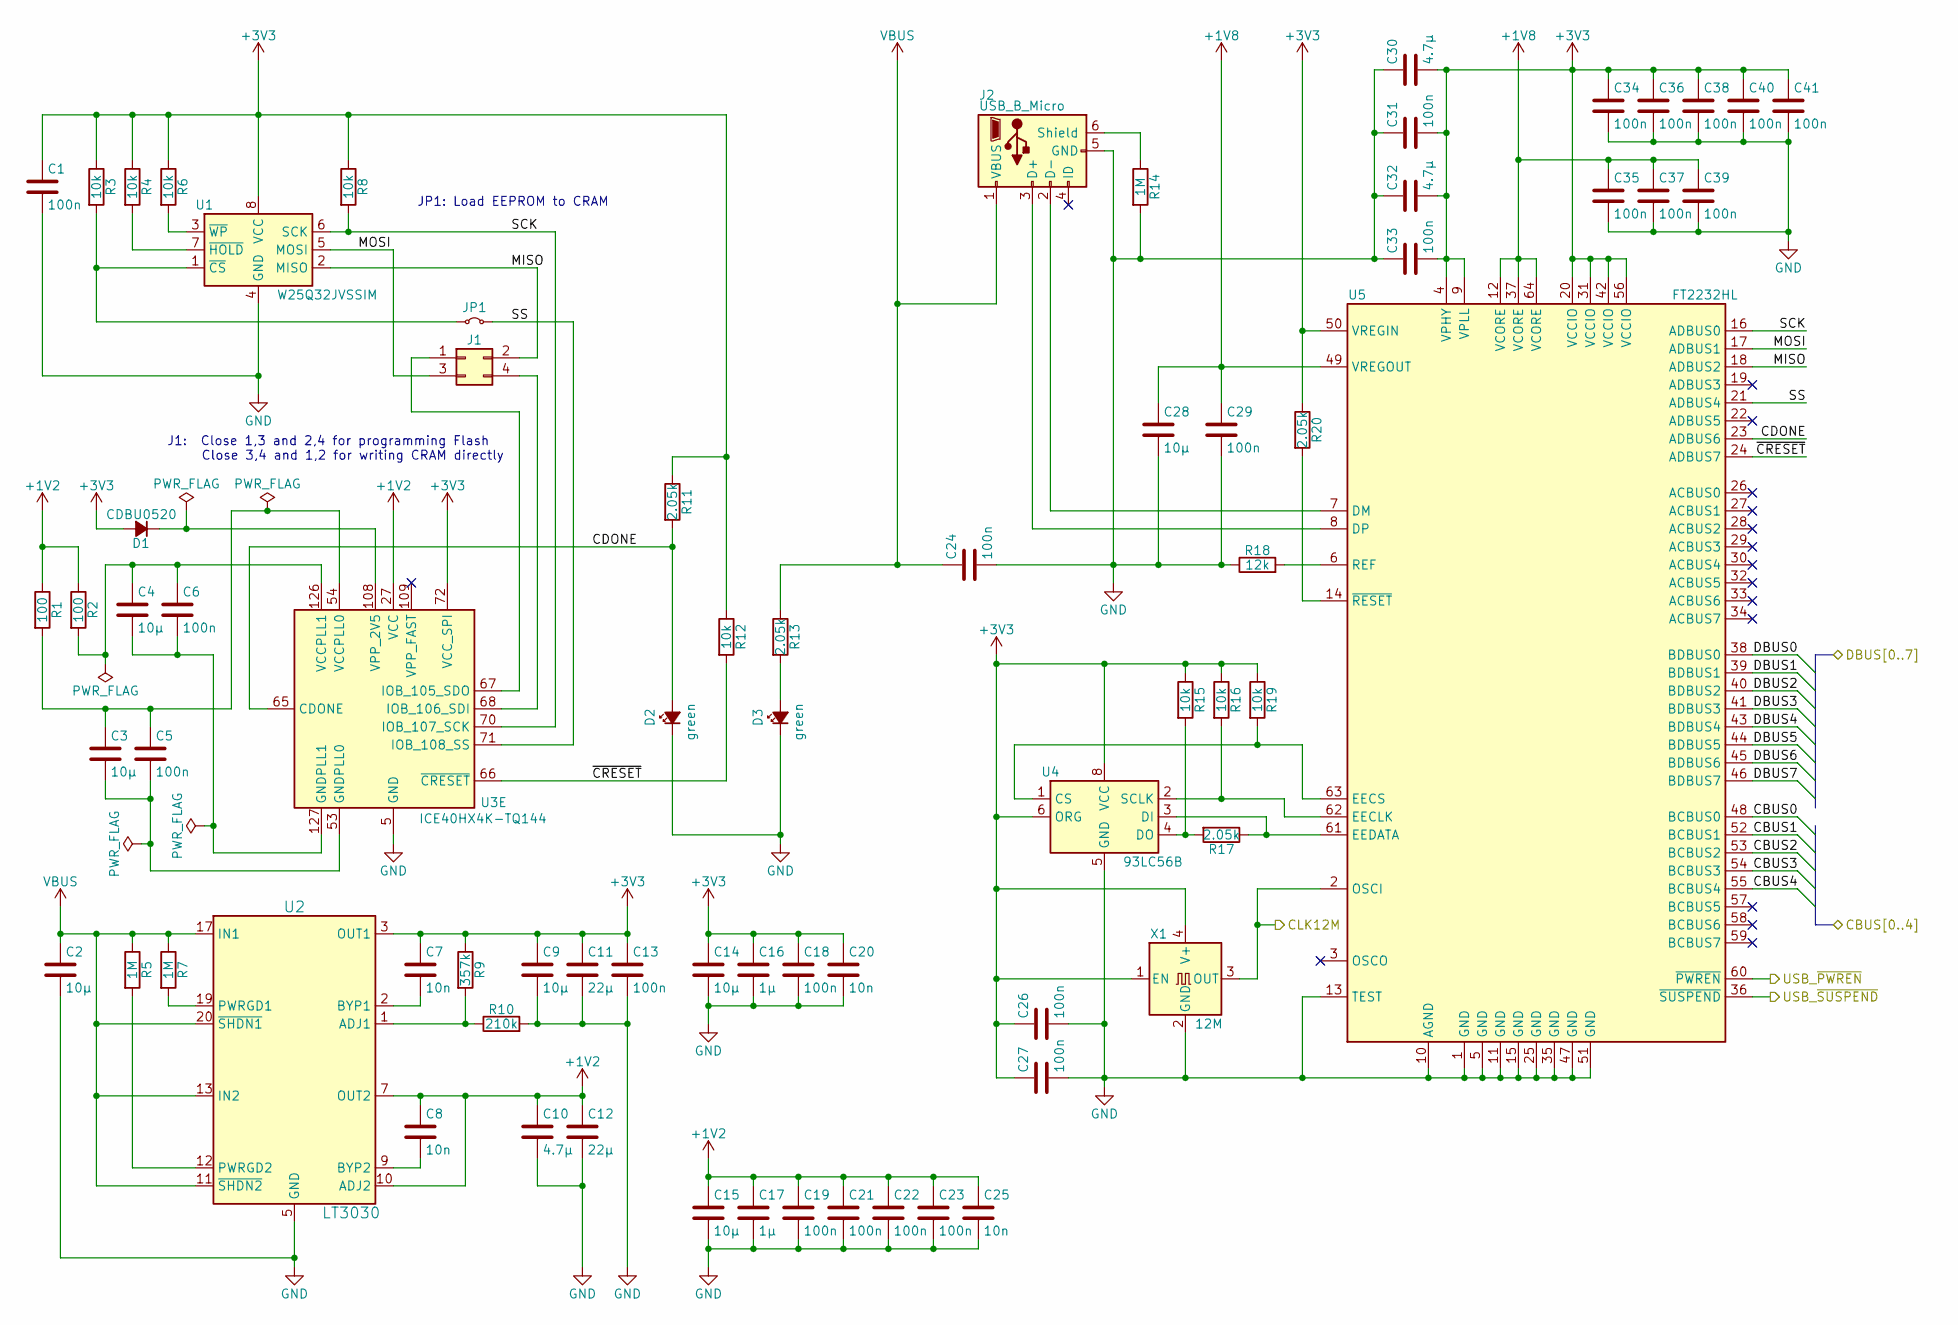
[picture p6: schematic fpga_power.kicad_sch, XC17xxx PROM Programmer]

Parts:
C1, C5, C6, C13, C18, C19, C21, C22, C23, C24, C26, C27, C29, C31, C33, C34, C35, C36, C37, C38, C39, C40, C41: 100n; C_0603_1608Metric
C2, C3, C4, C9, C14, C15, C28: 10µ; C_0603_1608Metric
C7, C8, C20, C25: 10n; C_0603_1608Metric
C10, C30, C32: 4.7µ; C_0603_1608Metric
C11, C12: 22µ; C_0805_2012Metric
C16, C17: 1µ; C_0603_1608Metric
D1: CDBU0520; D_0603_1608Metric
D2, D3: green; LED_0805_2012Metric
J1: Conn_02x02_Odd_Even; PinHeader_2x02_P2.54mm_Vertical
J2: USB_B_Micro; USB_Micro-B_Molex-105017-0001
JP1: Jumper_2_Small_Bridged; TestPoint_2Pads_Pitch2.54mm_Drill0.8mm
R1, R2: 100; R_0603_1608Metric
R3, R4, R6, R8, R12, R15, R16, R19: 10k; R_0603_1608Metric
R5, R7, R14: 1M; R_0603_1608Metric
R9: 357k; R_0603_1608Metric
R10: 210k; R_0603_1608Metric
R11, R13, R17, R20: 2.05k; R_0603_1608Metric
R18: 12k; R_0603_1608Metric
U1: W25Q32JVSSIM; SOIC-8W_5.3x5.3mm_P1.27mm
U2: LT3030; ETSSOP-20-1EP_4.4x6.5mm_P0.65mm_EP3x4.2mm
U3: ICE40HX4K-TQ144; TQFP-144_20x20mm_P0.5mm
U4: 93LC56B; SOIC-8_3.9x4.9mm_P1.27mm
U5: FT2232HL; LQFP-64_10x10mm_P0.5mm
X1: 12M; Oscillator_SMD_EuroQuartz_XO32-4Pin_3.2x2.5mm

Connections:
+1V2: C8.1, C10.1, C12.1, C15.1, C17.1, C19.1, C21.1, C22.1, C23.1, C25.1, R1.1, R2.1, U2.7 (OUT2), U2.8 (OUT2), U2.10 (ADJ2), U3.27 (VCC), U3.40 (VCC), U3.92 (VCC), U3.111 (VCC)
+1V8: C28.1, C29.1, C35.1, C37.1, C39.1, U5.12 (VCORE), U5.37 (VCORE), U5.49 (VREGOUT), U5.64 (VCORE)
+3V3: C1.1, C7.1, C9.1, C11.1, C13.1, C14.1, C16.1, C18.1, C20.1, C26.1, C27.1, C30.2, C31.2, C32.2, C33.2, C34.1, C36.1, C38.1, C40.1, C41.1, D1.2 (A), R3.1, R4.1, R6.1, R8.1, R9.1, R11.1, R12.1, R15.1, R16.1, R19.1, R20.1, U1.8 (VCC), U2.3 (OUT1), U2.4 (OUT1), U3.72 (VCC_SPI), U4.6 (ORG), U4.8 (VCC), U5.4 (VPHY), U5.9 (VPLL), U5.20 (VCCIO), U5.31 (VCCIO), U5.42 (VCCIO), U5.50 (VREGIN), U5.56 (VCCIO), X1.1 (EN), X1.4 (V+); also elsewhere on the board
/FPGA Power/CBUS0: U5.48 (BCBUS0); also elsewhere on the board
/FPGA Power/CBUS1: U5.52 (BCBUS1); also elsewhere on the board
/FPGA Power/CBUS2: U5.53 (BCBUS2); also elsewhere on the board
/FPGA Power/CBUS3: U5.54 (BCBUS3); also elsewhere on the board
/FPGA Power/CBUS4: U5.55 (BCBUS4); also elsewhere on the board
/FPGA Power/CDONE: D2.2 (A), R11.2, U3.65 (CDONE), U5.23 (ADBUS6)
/FPGA Power/DBUS0: U5.38 (BDBUS0); also elsewhere on the board
/FPGA Power/DBUS1: U5.39 (BDBUS1); also elsewhere on the board
/FPGA Power/DBUS2: U5.40 (BDBUS2); also elsewhere on the board
/FPGA Power/DBUS3: U5.41 (BDBUS3); also elsewhere on the board
/FPGA Power/DBUS4: U5.43 (BDBUS4); also elsewhere on the board
/FPGA Power/DBUS5: U5.44 (BDBUS5); also elsewhere on the board
/FPGA Power/DBUS6: U5.45 (BDBUS6); also elsewhere on the board
/FPGA Power/DBUS7: U5.46 (BDBUS7); also elsewhere on the board
/FPGA Power/MISO: J1.2, U1.2 (MISO), U5.18 (ADBUS2)
/FPGA Power/MOSI: J1.3, U1.5 (MOSI), U5.17 (ADBUS1)
/FPGA Power/SCK: R8.2, U1.6 (SCK), U3.70 (IOB_107_SCK), U5.16 (ADBUS0)
/FPGA Power/SS: JP1.2 (B), U3.71 (IOB_108_SS), U5.21 (ADBUS4)
/FPGA Power/USB_~PWREN: U5.60 (~PWREN); also elsewhere on the board
/FPGA Power/USB_~SUSPEND: U5.36 (~SUSPEND); also elsewhere on the board
/FPGA Power/~CRESET: R12.2, U3.66 (~CRESET), U5.24 (ADBUS7)
/FPGA/CLK12M: U5.2 (OSCI), X1.3 (OUT); also elsewhere on the board
GND: C1.2, C2.2, C9.2, C10.2, C11.2, C12.2, C13.2, C14.2, C15.2, C16.2, C17.2, C18.2, C19.2, C20.2, C21.2, C22.2, C23.2, C24.2, C25.2, C26.2, C27.2, C28.2, C29.2, C30.1, C31.1, C32.1, C33.1, C34.2, C35.2, C36.2, C37.2, C38.2, C39.2, C40.2, C41.2, D2.1 (K), D3.1 (K), J2.5 (GND), R10.2, R14.2, R18.1, U1.4 (GND), U2.5 (GND), U2.6 (GND), U2.15 (GND), U2.16 (GND), U2.21 (GND), U3.5 (GND), U3.13 (GND), U3.14 (GND), U3.59 (GND), U3.69 (GND), U3.86 (GND), U3.103 (GND), U3.132 (GND), U3.140 (GND), U4.5 (GND), U5.1 (GND), U5.5 (GND), U5.10 (AGND), U5.11 (GND), U5.13 (TEST), U5.15 (GND), U5.25 (GND), U5.35 (GND), U5.47 (GND), U5.51 (GND), X1.2 (GND); also elsewhere on the board
unnamed: D1.1 (K), U3.108 (VPP_2V5)
unnamed: D3.2 (A), R13.2
unnamed: J1.1, U3.67 (IOB_105_SDO)
unnamed: J1.4, U3.68 (IOB_106_SDI)
unnamed: J2.3 (D+), U5.8 (DP)
unnamed: J2.2 (D-), U5.7 (DM)
unnamed: J2.6 (Shield), R14.1
unnamed: JP1.1 (A), R3.2, U1.1 (~CS)
unnamed: R4.2, U1.7 (~HOLD)
unnamed: R6.2, U1.3 (~WP)
unnamed: R9.2, R10.1, U2.1 (ADJ1)
unnamed: C7.2, U2.2 (BYP1)
unnamed: C8.2, U2.9 (BYP2)
unnamed: R7.2, U2.19 (PWRGD1)
unnamed: R5.2, U2.12 (PWRGD2)
unnamed: C3.2, C5.2, U3.53 (GNDPLL0)
unnamed: C4.2, C6.2, U3.127 (GNDPLL1)
unnamed: C3.1, C5.1, R1.2, U3.54 (VCCPLL0)
unnamed: C4.1, C6.1, R2.2, U3.126 (VCCPLL1)
unnamed: R19.2, U4.1 (CS), U5.63 (EECS)
unnamed: R17.1, U4.3 (DI), U5.61 (EEDATA)
unnamed: R15.2, R17.2, U4.4 (DO)
unnamed: R16.2, U4.2 (SCLK), U5.62 (EECLK)
unnamed: R18.2, U5.6 (REF)
unnamed: R20.2, U5.14 (~RESET)
VBUS: C2.1, C24.1, J2.1 (VBUS), R5.1, R7.1, R13.1, U2.11 (~SHDN2), U2.13 (IN2), U2.14 (IN2), U2.17 (IN1), U2.18 (IN1), U2.20 (~SHDN1); also elsewhere on the board

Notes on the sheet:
JP1: Load EEPROM to CRAM
J1: Close 1,3 and 2,4 for programming Flash Close 3,4 and 1,2 for writing CRAM directly

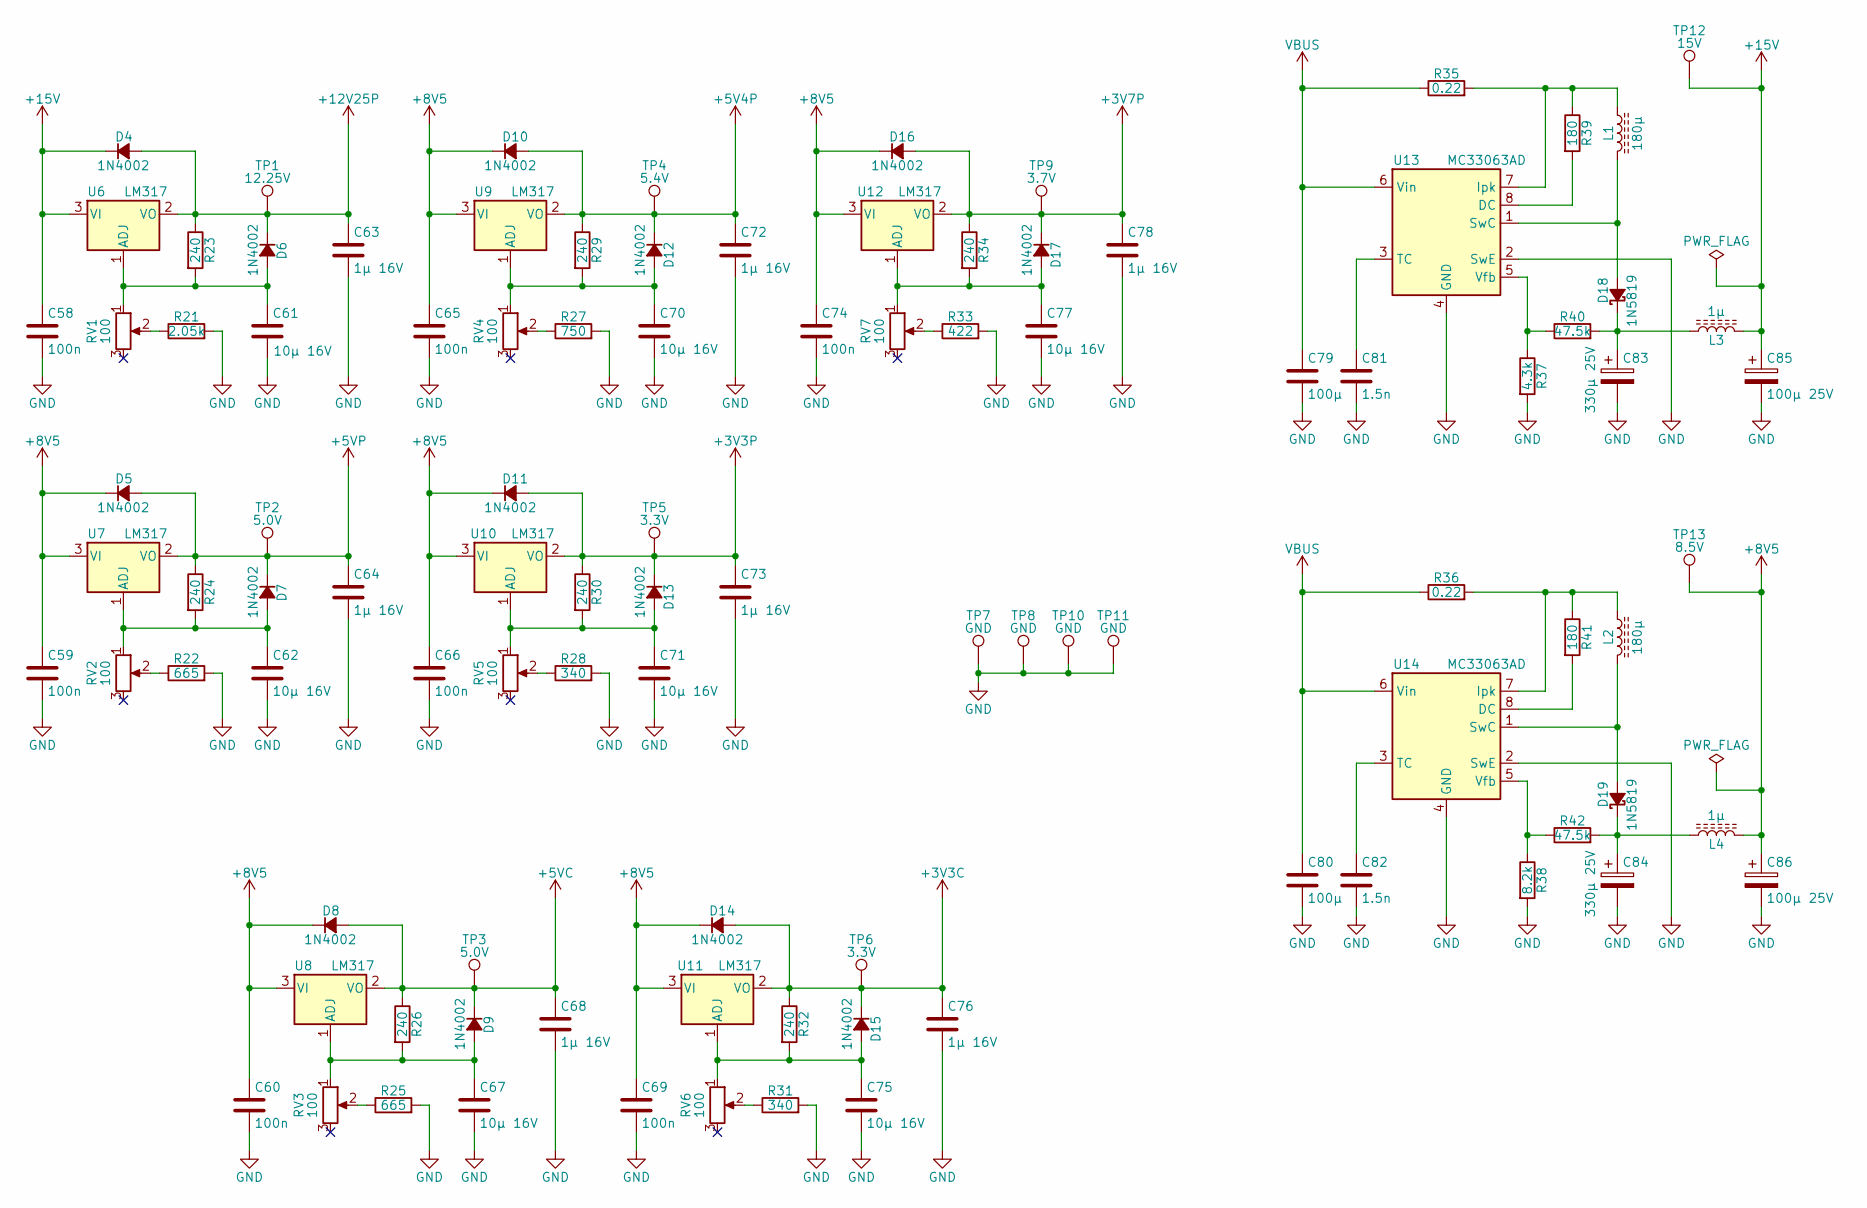
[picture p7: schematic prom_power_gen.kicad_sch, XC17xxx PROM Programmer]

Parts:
C58, C59, C60, C65, C66, C69, C74: 100n; C_0603_1608Metric
C61, C62, C67, C70, C71, C75, C77: 10µ 16V; C_1206_3216Metric
C63, C64, C68, C72, C73, C76, C78: 1µ 16V; C_0603_1608Metric
C79, C80: 100µ; C_1206_3216Metric
C81, C82: 1.5n; C_0603_1608Metric
C83, C84: 330µ 25V; CP_Elec_8x10.5
C85, C86: 100µ 25V; CP_Elec_6.3x7.7
D4, D5, D6, D7, D8, D9, D10, D11, D12, D13, D14, D15, D16, D17: 1N4002; D_MELF
D18, D19: 1N5819; D_SOD-123
L1, L2: 180µ; L_7.3x7.3_H4.5
L3, L4: 1µ; L_0805_2012Metric_Pad1.15x1.40mm_HandSolder
R21: 2.05k; R_0603_1608Metric
R22, R25: 665; R_0603_1608Metric
R23, R24, R26, R29, R30, R32, R34: 240; R_0603_1608Metric
R27: 750; R_0603_1608Metric
R28, R31: 340; R_0603_1608Metric
R33: 422; R_0603_1608Metric
R35, R36: 0.22; R_2512_6332Metric
R37: 4.3k; R_0603_1608Metric
R38: 8.2k; R_0603_1608Metric
R39, R41: 180; R_0603_1608Metric
R40, R42: 47.5k; R_0603_1608Metric
RV1, RV2, RV3, RV4, RV5, RV6, RV7: 100; Potentiometer_Bourns_3296W_Vertical
TP1: 12.25V; TestPoint_Keystone_5010-5014_Multipurpose
TP2, TP3: 5.0V; TestPoint_Keystone_5010-5014_Multipurpose
TP4: 5.4V; TestPoint_Keystone_5010-5014_Multipurpose
TP5, TP6: 3.3V; TestPoint_Keystone_5010-5014_Multipurpose
TP7, TP8, TP10, TP11: GND; TestPoint_Keystone_5010-5014_Multipurpose
TP9: 3.7V; TestPoint_Keystone_5010-5014_Multipurpose
TP12: 15V; TestPoint_Keystone_5010-5014_Multipurpose
TP13: 8.5V; TestPoint_Keystone_5010-5014_Multipurpose
U6, U7, U8, U9, U10, U11, U12: LM317; SOT-223-3_TabPin2
U13, U14: MC33063AD; SOIC-8_3.9x4.9mm_P1.27mm

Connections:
+3V3C: C76.1, D14.2 (A), D15.1 (K), R32.1, TP6.1, U11.2 (VO); also elsewhere on the board
+3V3P: C73.1, D11.2 (A), D13.1 (K), R30.1, TP5.1, U10.2 (VO); also elsewhere on the board
+3V7P: C78.1, D16.2 (A), D17.1 (K), R34.1, TP9.1, U12.2 (VO); also elsewhere on the board
+5V4P: C72.1, D10.2 (A), D12.1 (K), R29.1, TP4.1, U9.2 (VO); also elsewhere on the board
+5VC: C68.1, D8.2 (A), D9.1 (K), R26.1, TP3.1, U8.2 (VO); also elsewhere on the board
+5VP: C64.1, D5.2 (A), D7.1 (K), R24.1, TP2.1, U7.2 (VO); also elsewhere on the board
+8V5: C59.1, C60.1, C65.1, C66.1, C69.1, C74.1, C86.1, D5.1 (K), D8.1 (K), D10.1 (K), D11.1 (K), D14.1 (K), D16.1 (K), L4.2, TP13.1, U7.3 (VI), U8.3 (VI), U9.3 (VI), U10.3 (VI), U11.3 (VI), U12.3 (VI)
+12V25P: C63.1, D4.2 (A), D6.1 (K), R23.1, TP1.1, U6.2 (VO); also elsewhere on the board
+15V: C58.1, C85.1, D4.1 (K), L3.2, TP12.1, U6.3 (VI)
GND: C58.2, C59.2, C60.2, C61.2, C62.2, C63.2, C64.2, C65.2, C66.2, C67.2, C68.2, C69.2, C70.2, C71.2, C72.2, C73.2, C74.2, C75.2, C76.2, C77.2, C78.2, C79.2, C80.2, C81.2, C82.2, C83.2, C84.2, C85.2, C86.2, R21.2, R22.2, R25.2, R27.2, R28.2, R31.2, R33.2, R37.2, R38.2, TP7.1, TP8.1, TP10.1, TP11.1, U13.2 (SwE), U13.4 (GND), U14.2 (SwE), U14.4 (GND); also elsewhere on the board
unnamed: C61.1, D6.2 (A), R23.2, RV1.1, U6.1 (ADJ)
unnamed: C62.1, D7.2 (A), R24.2, RV2.1, U7.1 (ADJ)
unnamed: C67.1, D9.2 (A), R26.2, RV3.1, U8.1 (ADJ)
unnamed: C70.1, D12.2 (A), R29.2, RV4.1, U9.1 (ADJ)
unnamed: C71.1, D13.2 (A), R30.2, RV5.1, U10.1 (ADJ)
unnamed: C75.1, D15.2 (A), R32.2, RV6.1, U11.1 (ADJ)
unnamed: C77.1, D17.2 (A), R34.2, RV7.1, U12.1 (ADJ)
unnamed: D18.2 (A), L1.2, U13.1 (SwC)
unnamed: C83.1, D18.1 (K), L3.1, R40.2
unnamed: D19.2 (A), L2.2, U14.1 (SwC)
unnamed: C84.1, D19.1 (K), L4.1, R42.2
unnamed: R21.1, RV1.2
unnamed: R22.1, RV2.2
unnamed: R25.1, RV3.2
unnamed: R27.1, RV4.2
unnamed: R28.1, RV5.2
unnamed: R31.1, RV6.2
unnamed: R33.1, RV7.2
unnamed: R39.2, U13.8 (DC)
unnamed: L1.1, R35.2, R39.1, U13.7 (Ipk)
unnamed: C81.1, U13.3 (TC)
unnamed: R37.1, R40.1, U13.5 (Vfb)
unnamed: R41.2, U14.8 (DC)
unnamed: L2.1, R36.2, R41.1, U14.7 (Ipk)
unnamed: C82.1, U14.3 (TC)
unnamed: R38.1, R42.1, U14.5 (Vfb)
VBUS: C79.1, C80.1, R35.1, R36.1, U13.6 (Vin), U14.6 (Vin); also elsewhere on the board

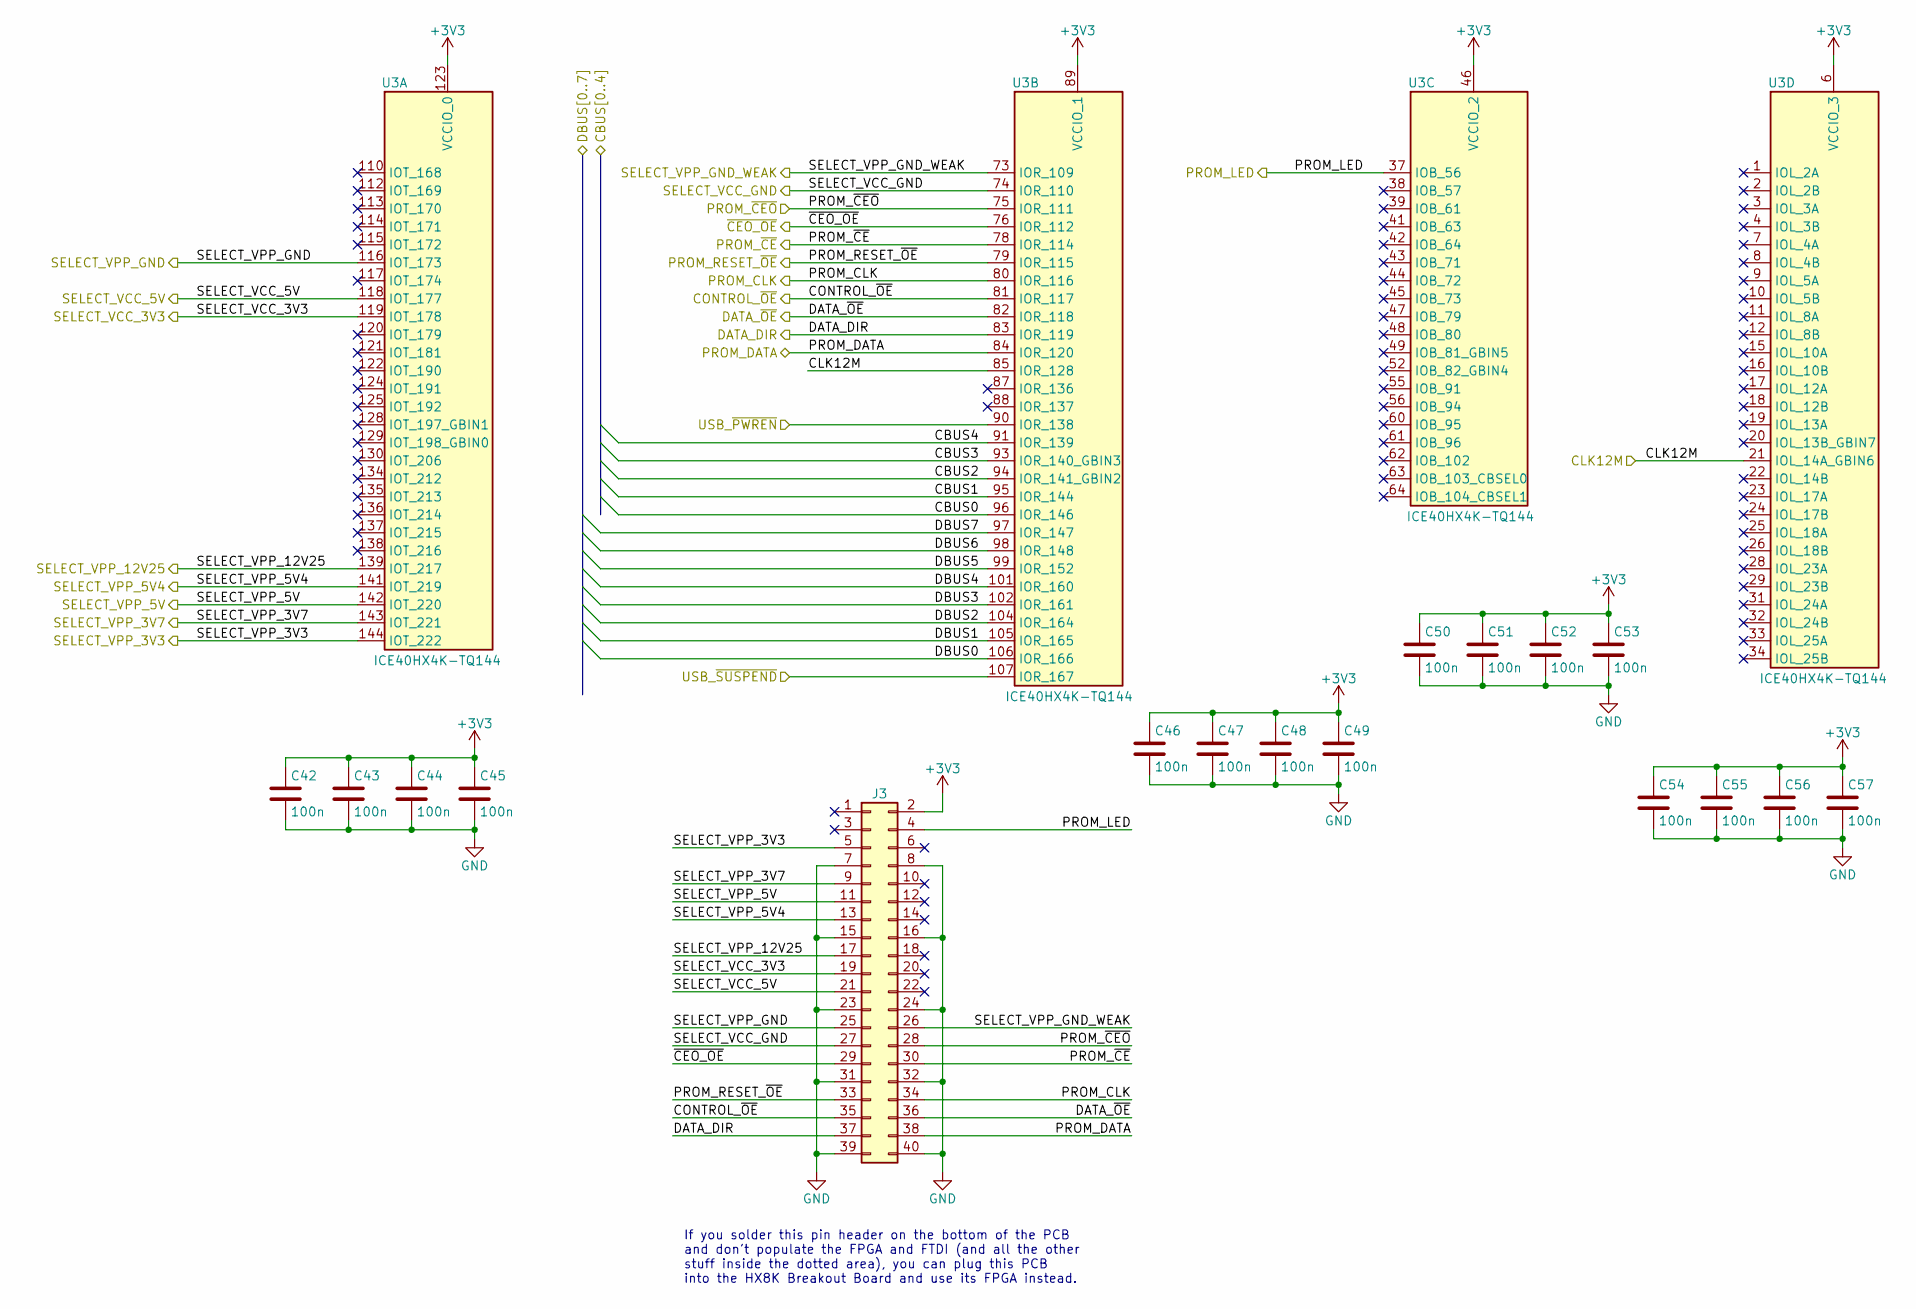
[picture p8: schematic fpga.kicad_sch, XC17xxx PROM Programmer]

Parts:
C42, C43, C44, C45, C46, C47, C48, C49, C50, C51, C52, C53, C54, C55, C56, C57: 100n; C_0603_1608Metric
J3: Conn_02x20_Odd_Even; PinHeader_2x20_P2.54mm_Vertical
U3: ICE40HX4K-TQ144; TQFP-144_20x20mm_P0.5mm

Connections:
+3V3: C42.1, C43.1, C44.1, C45.1, C46.1, C47.1, C48.1, C49.1, C50.1, C51.1, C52.1, C53.1, C54.1, C55.1, C56.1, C57.1, J3.2, U3.6 (VCCIO_3), U3.30 (VCCIO_3), U3.46 (VCCIO_2), U3.57 (VCCIO_2), U3.89 (VCCIO_1), U3.100 (VCCIO_1), U3.123 (VCCIO_0), U3.131 (VCCIO_0); also elsewhere on the board
/FPGA Power/CBUS0: U3.96 (IOR_146); also elsewhere on the board
/FPGA Power/CBUS1: U3.95 (IOR_144); also elsewhere on the board
/FPGA Power/CBUS2: U3.94 (IOR_141_GBIN2); also elsewhere on the board
/FPGA Power/CBUS3: U3.93 (IOR_140_GBIN3); also elsewhere on the board
/FPGA Power/CBUS4: U3.91 (IOR_139); also elsewhere on the board
/FPGA Power/DBUS0: U3.106 (IOR_166); also elsewhere on the board
/FPGA Power/DBUS1: U3.105 (IOR_165); also elsewhere on the board
/FPGA Power/DBUS2: U3.104 (IOR_164); also elsewhere on the board
/FPGA Power/DBUS3: U3.102 (IOR_161); also elsewhere on the board
/FPGA Power/DBUS4: U3.101 (IOR_160); also elsewhere on the board
/FPGA Power/DBUS5: U3.99 (IOR_152); also elsewhere on the board
/FPGA Power/DBUS6: U3.98 (IOR_148); also elsewhere on the board
/FPGA Power/DBUS7: U3.97 (IOR_147); also elsewhere on the board
/FPGA Power/USB_~PWREN: U3.90 (IOR_138); also elsewhere on the board
/FPGA Power/USB_~SUSPEND: U3.107 (IOR_167); also elsewhere on the board
/FPGA/CLK12M: U3.21 (IOL_14A_GBIN6), U3.85 (IOR_128); also elsewhere on the board
/FPGA/CONTROL_~OE: J3.35, U3.81 (IOR_117); also elsewhere on the board
/FPGA/DATA_DIR: J3.37, U3.83 (IOR_119); also elsewhere on the board
/FPGA/DATA_~OE: J3.36, U3.82 (IOR_118); also elsewhere on the board
/FPGA/PROM_CLK: J3.34, U3.80 (IOR_116); also elsewhere on the board
/FPGA/PROM_DATA: J3.38, U3.84 (IOR_120); also elsewhere on the board
/FPGA/PROM_LED: J3.4, U3.37 (IOB_56); also elsewhere on the board
/FPGA/PROM_RESET_~OE: J3.33, U3.79 (IOR_115); also elsewhere on the board
/FPGA/PROM_~CEO: J3.28, U3.75 (IOR_111); also elsewhere on the board
/FPGA/PROM_~CE: J3.30, U3.78 (IOR_114); also elsewhere on the board
/FPGA/SELECT_VCC_3V3: J3.19, U3.119 (IOT_178); also elsewhere on the board
/FPGA/SELECT_VCC_5V: J3.21, U3.118 (IOT_177); also elsewhere on the board
/FPGA/SELECT_VCC_GND: J3.27, U3.74 (IOR_110); also elsewhere on the board
/FPGA/SELECT_VPP_3V3: J3.5, U3.144 (IOT_222); also elsewhere on the board
/FPGA/SELECT_VPP_3V7: J3.9, U3.143 (IOT_221); also elsewhere on the board
/FPGA/SELECT_VPP_5V: J3.11, U3.142 (IOT_220); also elsewhere on the board
/FPGA/SELECT_VPP_5V4: J3.13, U3.141 (IOT_219); also elsewhere on the board
/FPGA/SELECT_VPP_12V25: J3.17, U3.139 (IOT_217); also elsewhere on the board
/FPGA/SELECT_VPP_GND: J3.25, U3.116 (IOT_173); also elsewhere on the board
/FPGA/SELECT_VPP_GND_WEAK: J3.26, U3.73 (IOR_109); also elsewhere on the board
/FPGA/~CEO_OE: J3.29, U3.76 (IOR_112); also elsewhere on the board
GND: C42.2, C43.2, C44.2, C45.2, C46.2, C47.2, C48.2, C49.2, C50.2, C51.2, C52.2, C53.2, C54.2, C55.2, C56.2, C57.2, J3.7, J3.8, J3.15, J3.16, J3.23, J3.24, J3.31, J3.32, J3.39, J3.40; also elsewhere on the board

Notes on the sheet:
If you solder this pin header on the bottom of the PCB and don't populate the FPGA and FTDI (and all the other stuff inside the dotted area), you can plug this PCB into the HX8K Breakout Board and use its FPGA instead.

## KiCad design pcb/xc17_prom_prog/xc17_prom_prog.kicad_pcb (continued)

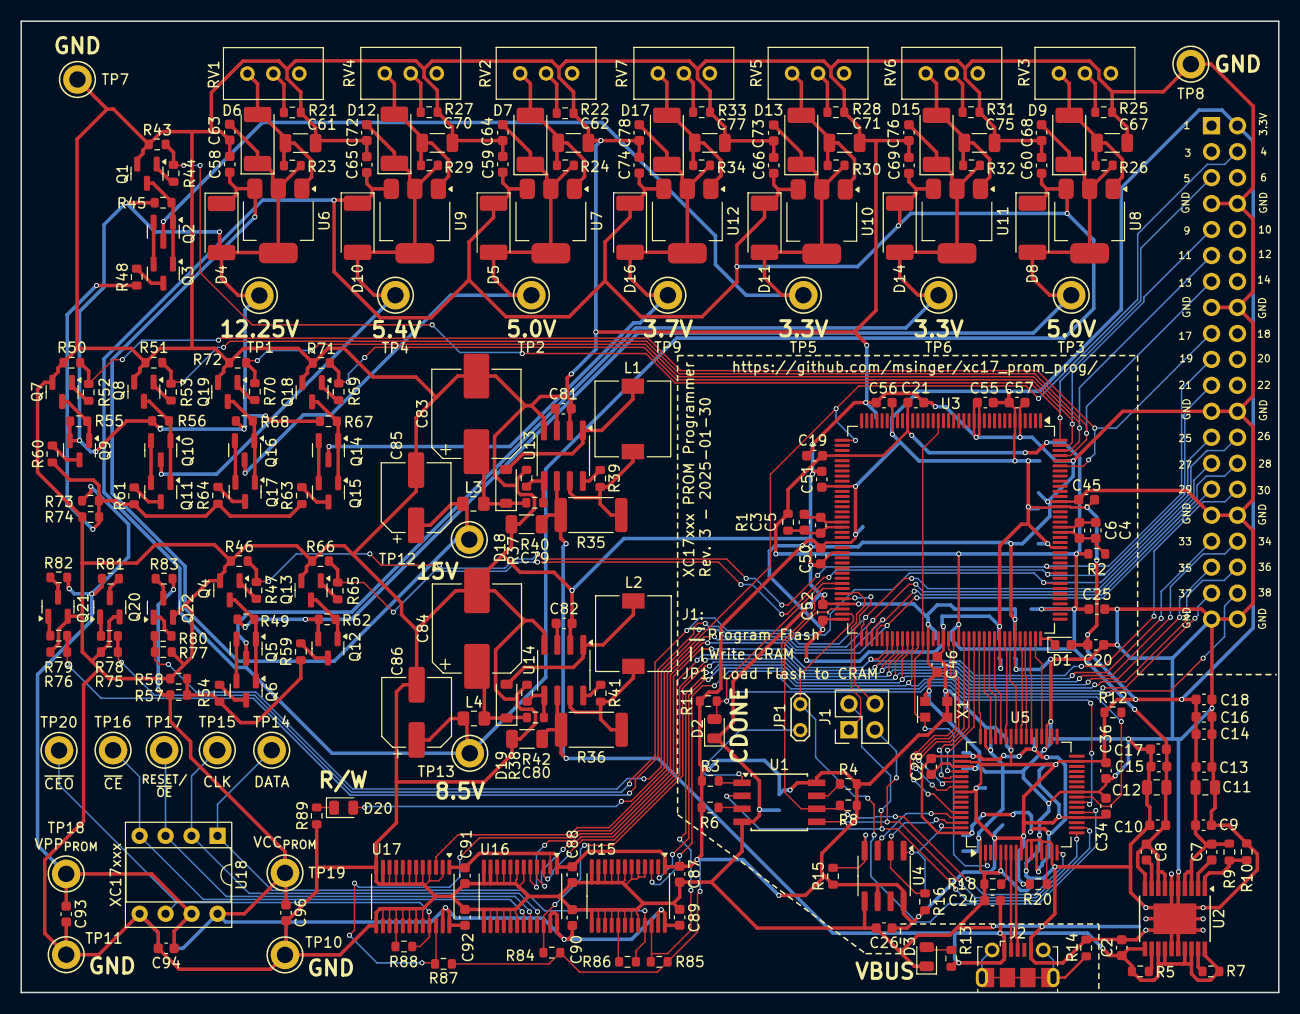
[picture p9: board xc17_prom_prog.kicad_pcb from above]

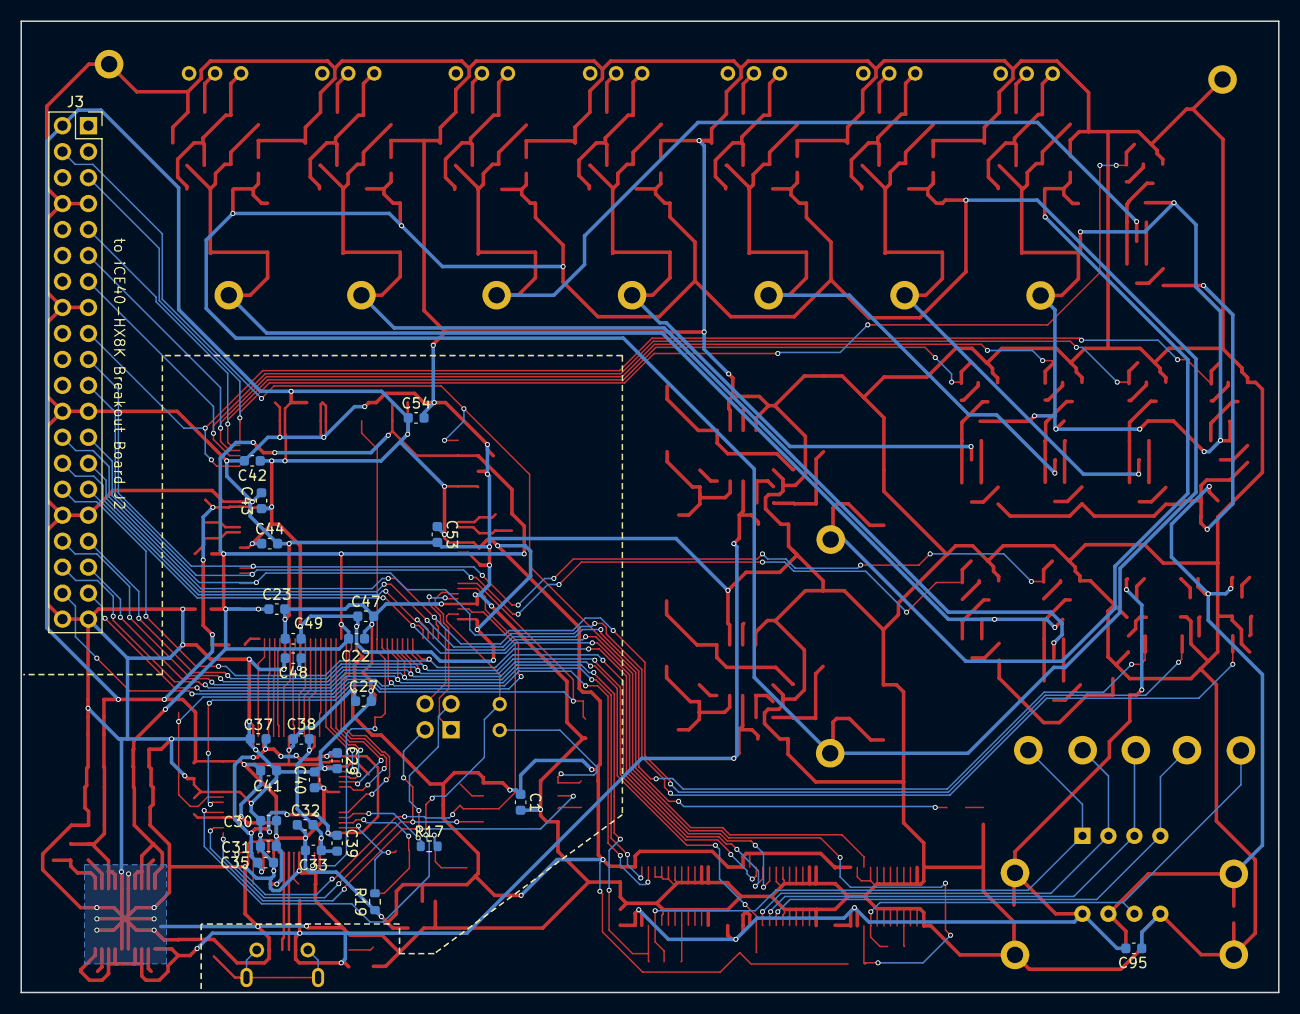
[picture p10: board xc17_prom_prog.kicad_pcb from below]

Board: 2 copper layers, 123.0 x 95.0 mm, 281 parts (26 on the bottom side), 149 nets.

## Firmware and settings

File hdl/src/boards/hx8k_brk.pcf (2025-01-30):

# For the iCE40HX-8K Breakout Board

# Clock
set_io clk12m       J3

# FTDI UART
set_io rx           B10
set_io tx           B12
set_io n_rts        B13
set_io n_cts        A15
set_io n_dtr        A16
set_io n_dsr        B14
set_io n_dcd        B15

# LEDs
set_io led[0]       R15
set_io led[1]       C3
set_io led[2]       B3
set_io led[3]       C4
set_io led[4]       C5
set_io led[5]       A1
set_io led[6]       A2
set_io led[7]       B4
set_io led[8]       B5

# Voltage select
set_io vcc_gnd      G16
set_io vcc_3v3      G14
set_io vcc_5v       J15
set_io vpp_gnd      H16
set_io vpp_gnd_weak G15
set_io vpp_3v3      P16
set_io vpp_3v7      N16
set_io vpp_5v       M16
set_io vpp_5v4      K15
set_io vpp_12v25    K14

# Level shifter DIR and /OE
set_io dir          C16
set_io n_oe         D14
set_io n_oe_ceo     F16
set_io n_oe_ctrl    D16

# PROM signals
set_io data         B16
set_io clk          D15
set_io n_ce         E14
set_io n_ceo        F15
set_io reset_oe     E16

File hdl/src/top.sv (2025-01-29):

`default_nettype none
`include "config.vh"

(* nolatches *)
(* top *)
module top(
		input  logic clk12m,

		input  logic rx,
		output logic tx,
		input  logic n_rts,
		output logic n_cts,
		input  logic n_dtr,
		output logic n_dsr = 0,
		output logic n_dcd = 0,

		output logic [`NUM_LEDS-1:0] led,

		output logic vcc_gnd,
		output logic vcc_3v3,
		output logic vcc_5v,
		output logic vpp_gnd,
		output logic vpp_gnd_weak,
		output logic vpp_3v3,
		output logic vpp_3v7,
		output logic vpp_5v,
		output logic vpp_5v4,
		output logic vpp_12v25,

		output logic dir,
		output logic n_oe,
		output logic n_oe_ceo = 0,
		output logic n_oe_ctrl,

		inout  logic data,
		output logic clk,
		output logic n_ce,
		input  logic n_ceo,
		output logic reset_oe
	);

	localparam int us = 12; /* ticks per microsecond */

	logic [20:0] led_delay;
	initial led       = 0;
	initial led_delay = 0;
	always_ff @(posedge clk12m) begin
		if (&led_delay)
			led[0] <= 0;
		else
			led_delay++;
		if (vcc_gnd || vcc_3v3 || vcc_5v ||
		    vpp_gnd || vpp_gnd_weak || vpp_3v3 || vpp_3v7 || vpp_5v || vpp_5v4 || vpp_12v25) begin
			led[0]    <= 1;
			led_delay  = 0;
		end
	end

	logic data_ena, data_out, data_in, data_s;
	cdc #(1) data_cdc (clk12m, data_in, data_s);
	SB_IO #(
		.PIN_TYPE('b 1010_00),
		.PULLUP(1)
	) data_io (
		.PACKAGE_PIN(data),
		.INPUT_CLK(clk12m),
		.D_IN_0(data_in),
		.D_OUT_0(data_out),
		.OUTPUT_ENABLE(data_ena)
	);

	logic n_ceo_in, n_ceo_s;
	cdc #(1) n_ceo_cdc (clk12m, n_ceo_in, n_ceo_s);
	SB_IO #(
		.PIN_TYPE('b 0000_00),
		.PULLUP(1)
	) n_ceo_io (
		.PACKAGE_PIN(n_ceo),
		.INPUT_CLK(clk12m),
		.D_IN_0(n_ceo_in)
	);

	initial dir       = 0;
	initial n_oe      = 1;
	initial n_oe_ctrl = 1;
	initial clk       = 0;
	initial n_ce      = 0;
	initial reset_oe  = 0;
	initial data_out  = 0;
	initial data_ena  = 0;

	initial vcc_gnd        = 0;
	initial vcc_3v3        = 0;
	initial vcc_5v         = 0;
	initial vpp_gnd        = 0;
	initial vpp_gnd_weak   = 0;
	initial vpp_3v3        = 0;
	initial vpp_3v7        = 0;
	initial vpp_5v         = 0;
	initial vpp_5v4        = 0;
	initial vpp_12v25      = 0;

	typedef logic [3:0]  pstate_t;
	typedef logic [1:0]  pmode_t;
	typedef logic [3:0]  pcmd_t;
	typedef logic [31:0] parg_t;
	typedef logic [16:0] pstep_t;
	typedef logic [1:0]  presult_t;

	localparam pstate_t pstate_idle        = 0;
	localparam pstate_t pstate_proc        = 1;
	localparam pstate_t pstate_prog_inc    = 2;
	localparam pstate_t pstate_prog_verify = 3;
	localparam pstate_t pstate_prog_write  = 4;
	localparam pstate_t pstate_prog_raise  = 5;
	localparam pstate_t pstate_prog_wait   = 6;
	localparam pstate_t pstate_prog_fall   = 7;
	localparam pstate_t pstate_prog_next   = 8;

	localparam pmode_t pmode_off       = 0;
	localparam pmode_t pmode_read      = 1;
	localparam pmode_t pmode_verify    = 2;
	localparam pmode_t pmode_prog      = 3;

	localparam pcmd_t pcmd_test_echo    = 0;
	localparam pcmd_t pcmd_test_voltage = 1;
	localparam pcmd_t pcmd_config_prom  = 2;
	localparam pcmd_t pcmd_query_info   = 3;
	localparam pcmd_t pcmd_pwroff       = 4;
	localparam pcmd_t pcmd_pwron_read   = 5;
	localparam pcmd_t pcmd_pwron_verify = 6;
	localparam pcmd_t pcmd_pwron_prog   = 7;
	localparam pcmd_t pcmd_read         = 8;
	localparam pcmd_t pcmd_prog_inc     = 9;
	localparam pcmd_t pcmd_prog_verify  = 10;
	localparam pcmd_t pcmd_prog_start   = 11;

	localparam presult_t presult_fail        = 0;
	localparam presult_t presult_early_ceo   = 1;
	localparam presult_t presult_success     = 2;
	localparam presult_t presult_success_ceo = 3;

	pstate_t  pstate;
	pmode_t   pmode;
	pcmd_t    pcmd;
	parg_t    parg;
	logic     p_seq, p_ack;
	pstep_t   pstep;
	presult_t presult;

	/*
	 * 5 volt device?
	 * If 1, the following voltages are being used:
	 *   - VCCread   = 5V
	 *   - VPPread   = 5V
	 *   - VCCverify = 5V
	 *   - VPPverify = 5.4V
	 * If 0, the following voltages are being used:
	 *   - VCCread   = 3.3V
	 *   - VPPread   = 3.3V
	 *   - VCCverify = 3.3V
	 *   - VPPverify = 3.7V
	 */
	logic dev5v;

	/*
	 * Device that uses 5 volt for programming?
	 * If 1, the following voltages are being used:
	 *   - VCCprog   = 5V
	 *   - VPP2      = 5.4V
	 *   - VCCnom    = 5V
	 *   - VPPnom    = 5V
	 * If 0, the following voltages are being used:
	 *   - VCCprog   = 3.3V
	 *   - VPP2      = 3.7V
	 *   - VCCnom    = 3.3V
	 *   - VPPnom    = 3.3V
	 */
	logic dev5v_prog;

	/* 1: Device uses 64 bit words.  0: Device used 32 bit words. */
	logic dev64bit;

	/* 1: Device is configured for active low reset.  0: Device is configured for active high reset. */
	logic inv_reset;

	/* Program pulse time and retry program pulse time in ticks. */
	logic [13:0] tpgm, tpgm1;

	/* Reset program pulse time in ticks. */
	logic [15:0] tprst;

	initial pstate     = pstate_idle;
	initial pmode      = pmode_off;
	initial p_seq      = 0;
	initial p_ack      = 0;
	initial presult    = presult_fail;
	initial dev5v      = 0;
	initial dev5v_prog = 0;
	initial dev64bit   = 0;
	initial inv_reset  = 0;

	task automatic disable_vcc();
		vcc_gnd <= 0;
		vcc_3v3 <= 0;
		vcc_5v  <= 0;
	endtask

	task automatic disable_vpp();
		vpp_gnd        <= 0;
		vpp_gnd_weak   <= 0;
		vpp_3v3        <= 0;
		vpp_3v7        <= 0;
		vpp_5v         <= 0;
		vpp_5v4        <= 0;
		vpp_12v25      <= 0;
	endtask

	task automatic disable_all();
		disable_vcc;
		disable_vpp;
		pmode = pmode_off;
	endtask

	task automatic pwr_read();
		if (dev5v) begin
			vcc_5v  <= 1;
			vpp_5v  <= 1;
		end else begin
			vcc_3v3 <= 1;
			vpp_3v3 <= 1;
		end
		pmode = pmode_read;
	endtask

	task automatic pwr_verify();
		if (dev5v) begin
			vcc_5v  <= 1;
			vpp_5v4 <= 1;
		end else begin
			vcc_3v3 <= 1;
			vpp_3v7 <= 1;
		end
		pmode = pmode_verify;
	endtask

	task automatic pwr_prog();
		if (dev5v_prog) begin
			vcc_5v  <= 1;
			vpp_5v  <= 1;
		end else begin
			vcc_3v3 <= 1;
			vpp_3v3 <= 1;
		end
		pmode = pmode_prog;
	endtask

	task automatic pwr_vpp_nominal();
		if (dev5v_prog)
			vpp_5v  <= 1;
		else
			vpp_3v3 <= 1;
	endtask

	task automatic pwr_vpp2();
		if (dev5v_prog)
			vpp_5v4 <= 1;
		else
			vpp_3v7 <= 1;
	endtask

	task automatic reset_prom_pins();
		dir       <= 0;
		n_oe      <= 1;
		n_oe_ctrl <= 1;
		clk       <= 0;
		n_ce      <= 0;
		reset_oe  <= 0;
		data_out  <= 0;
		data_ena  <= 0;
	endtask

	task automatic reset_prom(input logic reset);
		if (inv_reset)
			reset_oe <= !reset;
		else
			reset_oe <= reset;
	endtask

	logic [5:0]  bit_pos;
	logic [11:0] byte_pos;
	logic [9:0]  word_count;
	logic [16:0] inc_count;
	logic        handle_reset;
	logic        cont_on_err;
	logic        inner_verify;
	logic [1:0]  retry_count;

	/*
	 * Data in prog_word and verify_word are bit swapped.
	 * For 32 bit devices, only [31:0] are used.
	 */
	logic [63:0] prog_word, verify_word;
	initial prog_word   = 0;
	initial verify_word = 0;

	/*
	 * Like prog_word, prog_word_tmp is bit swapped.
	 * For 32 bit devices, only [63:32] are used.
	 */
	logic [63:0] prog_word_tmp;
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

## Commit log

2024-11-29 Fix MOSFETs
    * Block MOSFET body diodes by placing two MOSFETs in anti series.
    * Connect PROM LED to pin header.
    * Add transistors to actively pull PROM VCC and VPP low.
    [bom.ods, fpga.kicad_sch, fpga_power.kicad_sch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]
2024-12-05 initial Verilog and C# code
    * Capable of reading Maufacturer and Device ID from PROM.
2024-12-08 Implement more precise voltage controls
    [bom.ods, fpga.kicad_sch, fpga_power.kicad_sch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]
2024-12-08 Fix pin numbers in code for new PCB rev
    [hx8k_brk.pcf, top.sv]
2024-12-29 Fix voltage over-/under-shots
    [bom.ods, prom_power_switch.kicad_sch, xc17_prom_prog.kicad_pcb]
2025-01-10 Implement read chip and read reset polarity
    [top.sv]
2025-01-29 Implement actual programming
    Bitstream is too big for the HX1K FPGA. Needed to use the HX8K Breakout
    Board. Will change the PCB to host an HX4K FPGA later.
    I successfully programmed my first XC17S20XL PROM chip with this commit!
    Reset polarity is not yet done.
    [top.sv]
2025-01-29 Remove unused components
    [fpga.kicad_sch, fpga_power.kicad_sch, prom.kicad_sch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]
2025-01-30 Migrate from HX1K to HX4K FPGA
    [bom.ods, fpga.kicad_sch, fpga_power.kicad_sch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]
2025-01-31 Document calibration and testing in README.md
2025-03-29 Ignore *.kicad_prl

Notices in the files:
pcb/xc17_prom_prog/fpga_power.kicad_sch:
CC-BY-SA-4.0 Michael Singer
